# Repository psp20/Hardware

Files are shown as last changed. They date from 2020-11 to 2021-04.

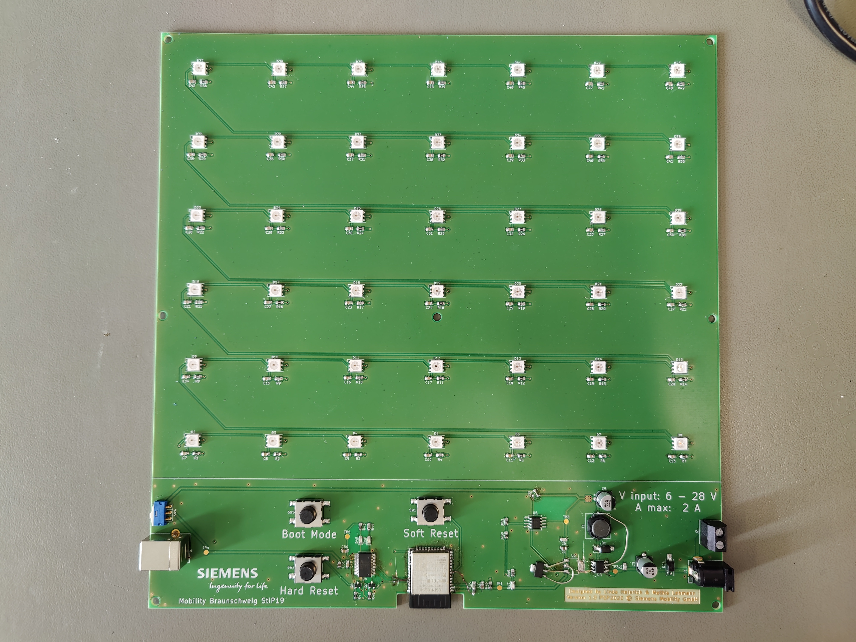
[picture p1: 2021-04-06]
Dokumentation/Anleitung/Bilder/Full.jpg

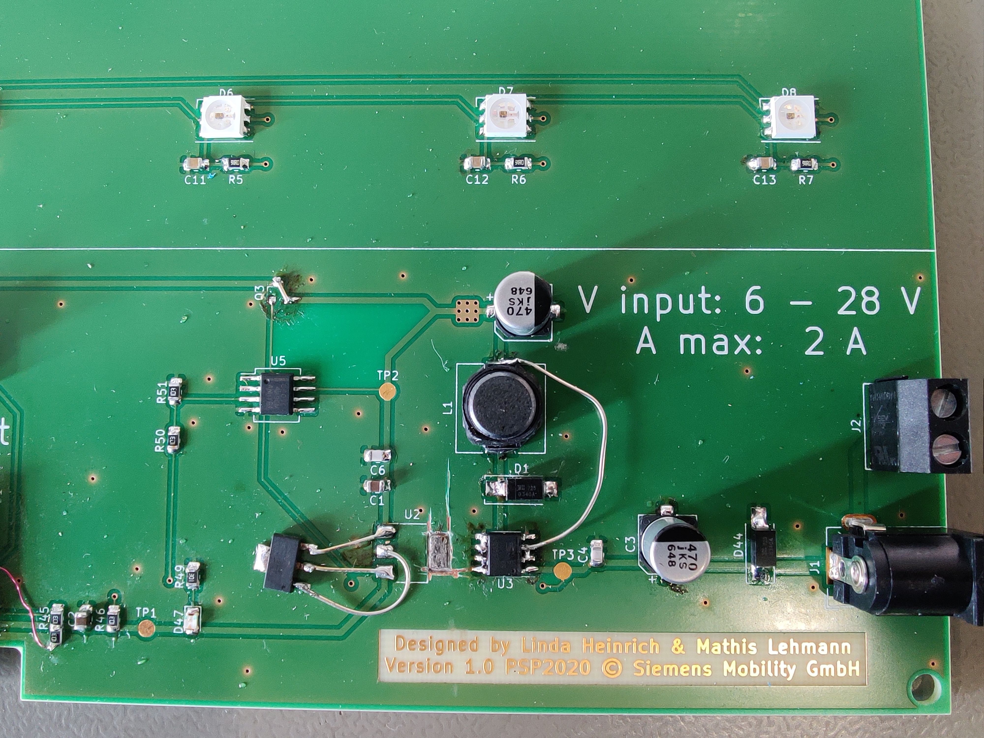
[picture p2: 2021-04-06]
Dokumentation/Anleitung/Bilder/PSU.jpg

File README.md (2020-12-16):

# Hardware
Vier Gewinnt Hardware Repository
## Schaltplan
* [x] Komponenten festlegen
* [x] Schaltplan fertigstellen
* [x] Sanity checks durchführen
* [x] BOM erstellen
## Platinenlayout
* [x] Größe festlegen
* [x] Footprints auswählen
* [x] Trace-routing fertigstellen
## Produktion
* [x] Produktionsmöglichkeiten klären
* [ ] Prototyp bestellen

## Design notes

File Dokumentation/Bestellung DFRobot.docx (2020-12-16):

# Bestellung bei DFRobot

1. DFRobot Prototyping Service aufrufen: Link (https://www.dfrobot.com/index.php?route=product/pcb)
2. Gerber Dateien hochladen –> PSP_Hardware_Gerber.zip
3. Einstellungen anpassen / überprüfen
  a. Layer: 2 Layer
  b. PCB Dimensions: 245 W * 250 L
  c. PCB Qty: 10
  d. Different Design(s): 1
  e. PCB Thickness: 1.6
  f. PCB Color: Black
  g. Surface Finish: HASL
  h. Copper Weight: 1oz
  i. Production Time: 5-6 working days
4. Add To Cart
5. Bestellung abschließen

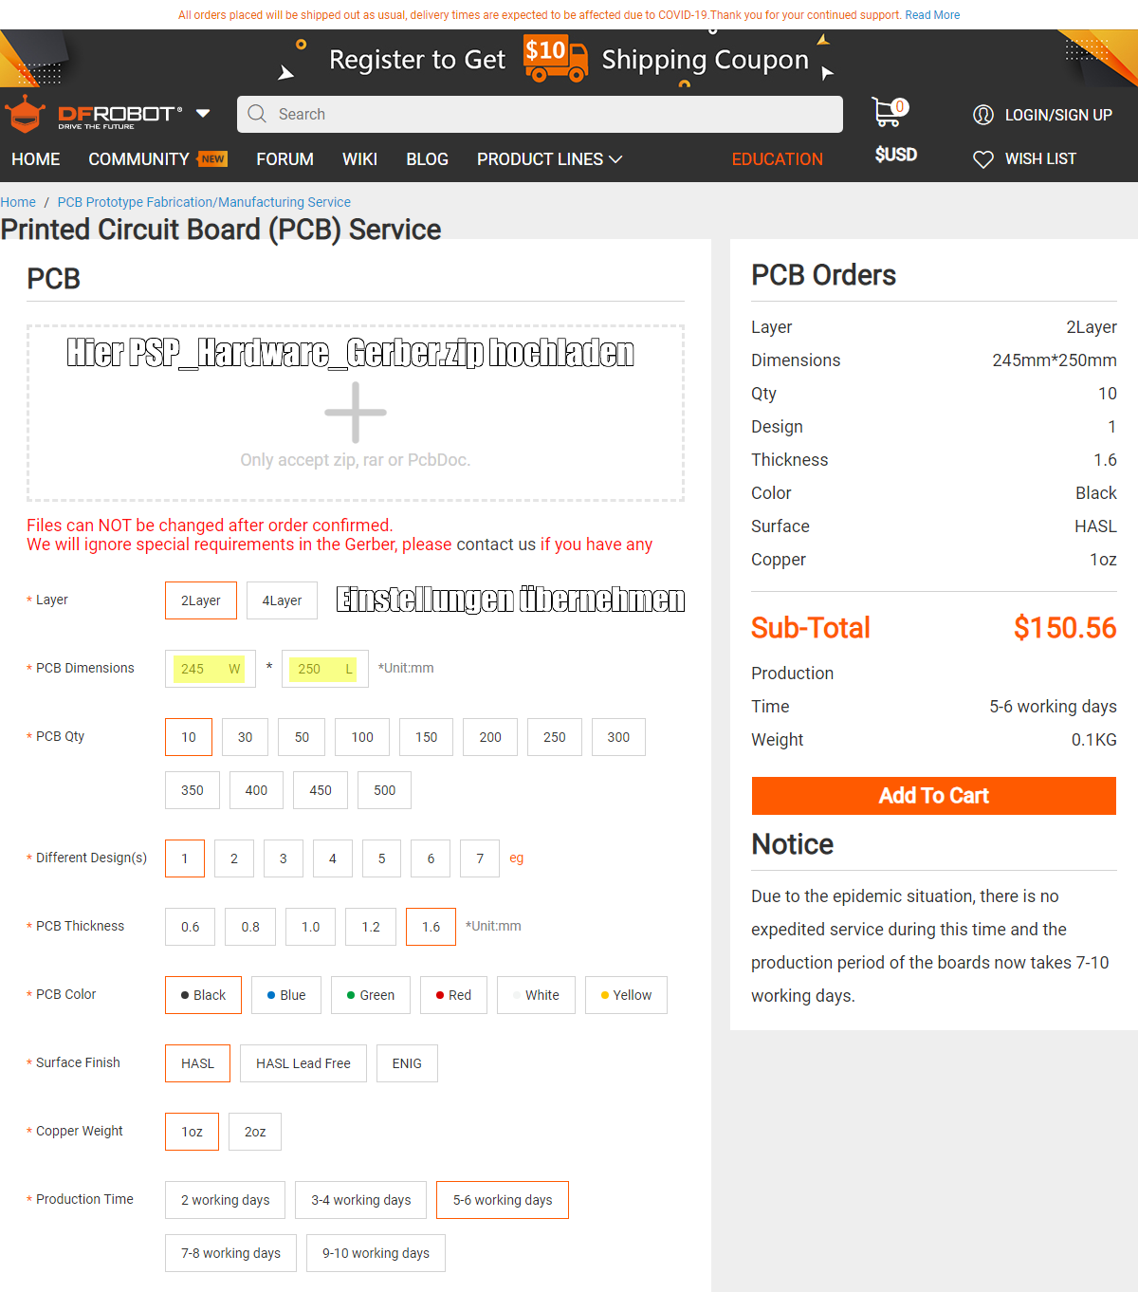
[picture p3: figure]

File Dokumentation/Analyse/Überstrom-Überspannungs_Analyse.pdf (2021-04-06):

## Risikoanalyse eines Überstrom- oder Überspannungsereignisses auf der

## Vier-Gewinnt-Platine

Mathis Lehmann
PSP20
mathis.lehmann@siemens.com Revision V1.0
2. März 2021

1

## Inhaltsverzeichnis

1 Einführung | 3
2 Rundsteckerhohlbuchse | 4
3 Terminal-block | 6
4 USB Typ B Buchse | 8
5 Revisionsverzeichnis | 9

2

## 1 Einführung

### 1.1 Abstrakt

Dieses Dokument befasst sich mit der Analyse eines Überstrom- oder Überspannungsereignisses und den Konsequenzen eines solchen Ereignisses. Es analysiert die Platine und deren Komponenten, welche die Form eines digitalen Vier-Gewinnt einnimmt und im Rahmen des Praxissemsterprojektes bei der Siemens Mobility GmbH von den Dualen Studenten des Jahrgangs 2019 erarbeitet wurden. Das hardwareseitige Produkt dieses Praxissemesters wird im Folgenden nur noch Platine genannt. Hierbei werden Konsequenzen einer eventuell auftretenden Überlast auf die Platine, die verbauten Komponenten und eventuelle Stromquellen betrachtet. Dies soll eine Entscheidung begründen, ob zusätzliche Sicherungsmaßnahmen auf Seiten der Platine zu empfehlen oder gar nötig sind.

### 1.2 Vorgehen

Im weiteren Verlauf dieses Dokuments werden folgendene Szenarien analysiert:

1. Verpolung der angelegten Spannung
2. Zu hohe angelegte Spannung seitens der Spannungsquelle
3. Zu hoher Strom aufgrund eines Fehlers auf der Platine
4. Spannungszusammenbruch auf Seite der Stromquelle

Diese werden jeweils unter einem der 3 Einspeisungspunkte der Platine analysiert:

1. Rundsteckerhohlbuchse
2. Terminal-block
3. USB Typ B Buchse

3

## 2 Rundsteckerhohlbuchse

### 2.1 Verpolung

Eine Verpolung der Rundsteckerhohlbuchse ist sehr unwahrscheinlich, da die Platine die standardisierte Hohlbuchsenbelegung benutzt. Diese benutzt den äußeren Mantel als negativen Pol und den geschützten Innenpin als positiven Pol. Jedoch gibt es Netzteile die dieser Belegung nicht folgen, da sich daraus früher diesen Herstellern gewisse Vorteile boten. Diese Netzteile sind selten, aber dennoch verfügbar und stellen damit ein Risiko für die Platine dar.
Im Falle einer Verpolung greift eine Schutzeinrichtung der Platine, eine Verpolungsdiode. Diese schließt die verkehrt gepolte Spannungsquelle kurz. Diese Diode ist in der Lage 3 Ampere dauerhaft kurzzuschließen. Hieraus ergeben sich folgende Szenarien:
1. Überlastabschaltung des Netzteils löst aus. In diesem Fall schaltet sich das Netzteil zum Selbstschutz aus. Eine Beschädigung der Platine ist höchst unwahrscheinlich, da die Diode eine maximale Belastung von 80 Ampere für 8,3 ms aushält, was ausreichend ist, um selbst überdimensionierte Netzteile in den Überlastzustand zu bringen. Die Diode bleibt davon ungeschädigt und die Platine kann nach beheben der Verpolung weitergenutzt werden.
2. Überlastabschaltung des Netzteils löst nicht aus. In diesem Fall gibt es 2 Unterszenarien:
(a) Netzteil liefert maximal 3 Ampere. In diesem Fall wird das Netzteil dauerhaft kurzgeschlossen, bis der Endbenutzer den Fehler bemerkt oder eine andere Sicherungseinrichtung greift. Die Platine bleibt unbeschädigt.
(b) Netzteil liefert mehr als 3 Ampere. In diesem Fall wird das Netzteil dauerhaft kurzgeschlossen, bis der Endbenutzer den Fehler bemerkt oder eine andere Sicherungseinrichtung greift. Jedoch wurde die Diode dauerhaft überlastet und stellt einen dauerhaften niederohmigen Kurzschluss dar.

### 2.2 Überspannung

Eine Überspannung tritt ab einer Eingangsspannung von 28 Volt auf. Je nach Höhe der Eingangsspannung gibt es hier 2 Fälle:

1. Eingangsspannung von unter 40 Volt. In diesem Fall wird duch die Spannung der Eingangskondensator beschädigt. Dieser wird nach kurzer Zeit das Elektrolyt entlüften und somit zu einem niederohmigen Widerstand, der nun die Spannungsquelle kurzschließt. Bis dies passiert, liegt am Step-Down Regler die Überspannung an. Dieser geht ab 29 Volt in die Abschaltung. Jedoch wird er ab 35 Volt beschädigt, welches sich bei diesem Bauteil als hochohmiger Fehler äußert.

4

2. Eingangsspannung von über 40 Volt. In diesem Fall wird die Diode leitend. Und begrenzt die Spannung auf 40 Volt. Die Beschädigungen aus Punkt 1 gelten weiterhin.

Ab diesem Punkt gelten die Unterszenarien aus 2.1 Unterpunkt 2a und 2b, jedoch weiterhin mit den Beschädigungen des jeweiligen Unterpunktes.

### 2.3 Überstrom

Ein Überstromereignis kann nur bei bei voheriger Beschädigung der Platine oder bei einer Überspannung auftreten. In diesem Fall greifen nur die Unterszenarien aus 2.2.

### 2.4 Spannungszusammenbruch

Sollte die Versorgungsspannung unter 7 Volt zusammenbrechen, schaltet sich der Step-Down Regler ab und aktiviert sich erst nach Erreichen von 7 Volt Eingangsspannung. Die Platine bleibt unbeschädigt.

5

## 3 Terminal-block

### 3.1 Verpolung

Im Falle einer Verpolung greift eine Schutzeinrichtung der Platine, eine Verpolungsdiode. Diese schließt die verkehrt gepolte Spannungsquelle kurz. Diese Diode ist in der Lage 3 Ampere dauerhaft kurzzuschließen. Hieraus ergeben sich folgende Szenarien:

1. Überlastabschaltung des Netzteils löst aus. In diesem Fall schaltet sich das Netzteil zum Selbstschutz aus. Eine Beschädigung der Platine ist höchst unwahrscheinlich, da die Diode eine maximale Belastung von 80 Ampere für 8,3 ms aushält, was ausreichend ist, um selbst überdimensionierte Netzteile in den Überlastzustand zu bringen. Die Diode bleibt davon ungeschädigt und die Platine kann nach beheben der Verpolung weitergenutzt werden.
2. Überlastabschaltung des Netzteils löst nicht aus. In diesem Fall gibt es 2 Unterszenarien:
(a) Netzteil liefert maximal 3 Ampere. In diesem Fall wird das Netzteil dauerhaft kurzgeschlossen, bis der Endbenutzer den Fehler bemerkt oder eine andere Sicherungseinrichtung greift. Die Platine bleibt unbeschädigt.
(b) Netzteil liefert mehr als 3 Ampere. In diesem Fall wird das Netzteil dauerhaft kurzgeschlossen, bis der Endbenutzer den Fehler bemerkt oder eine andere Sicherungseinrichtung greift. Jedoch wurde die Diode dauerhaft überlastet und stellt einen dauerhaften niederohmigen Kurzschluss dar.

### 3.2 Überspannung

Eine Überspannung tritt ab einer Eingangsspannung von 28 Volt auf. Je nach Höhe der Eingangsspannung gibt es hier 2 Fälle:

1. Eingangsspannung von unter 40 Volt. In diesem Fall wird duch die Spannung der Eingangskondensator beschädigt. Dieser wird nach kurzer Zeit das Elektrolyt entlüften und somit zu einem niederohmigen Widerstand, der nun die Spannungsquelle kurzschließt. Bis dies passiert, liegt am Step-Down Regler die Spannung an. Dieser geht ab 29 Volt in die Abschaltung. Jedoch wird er ab 35 Volt beschädigt, welches sich bei diesem Bauteil als hochohmiger Fehler äußert.
2. Eingangsspannung von über 40 Volt. In diesem Fall wird die Diode leitend. Und begrenzt die Spannung auf 40 Volt. Die Beschädigungen aus Punkt 1 gelten weiterhin.

Ab diesem Punkt gelten die Unterszenarien aus 3.1 Unterpunkt 2a und 2b, jedoch weiterhin mit den Beschädigungen des jeweiligen Unterpunktes.

6

### 3.3 Überstrom

Ein Überstromereignis kann nur bei bei voheriger Beschädigung der Platine oder bei einer Überspannung auftreten. In diesem Fall greifen nur die Unterszenarien aus 3.2.

### 3.4 Spannungszusammenbruch

Sollte die Versorgungsspannung unter 7 Volt zusammenbrechen schaltet, sich der Step-Down Regler ab und aktiviert sich erst nach Erreichen von 7 Volt Eingangsspannung. Die Platine bleibt unbeschädigt.

7

## 4 USB Typ B Buchse

### 4.1 Verpolung

Bei einer Verpolung des USB Anschlusses wird der P-Channel MOSFET von Drain zu Source betrieben. Daher ist dieser nicht leitend und es liegt keine Spannung an anderen Bauteilen an, die diese beschädigen könnte.
Wenn jedoch das Vier Gewinnt im Programmiermodus verpolt wird, kann der USB Seriell Wandler beschädigt werden.

### 4.2 Überspannung

Bei Überspannung sind zuerste die LEDs zu betrachten. Da die Versorgung über USB ohne Regulierung direkt auf die 5 Volt Versorungsschiene der Platine geht, liegt jede Überspannung direkt an den LEDs an. Diese sind spezifiziert auf einer Versorungsspannung von 5,3 Volt. Über diese Spannung hinaus können diese beschädigt werden. Jedoch ist nicht abzusehen, ob diese LEDs niederohmig oder hochohmig werden.
Bis 18 Volt bleibt der Microcontroller jedoch geschützt, da dieser hinter einer Regulierungsstufe hängt.
Über 18 Volt hinaus ist die Platine mit hoher Wahrscheinlickeit komplett zerstört.

### 4.3 Überstrom

Ein Überstromereignis kann nur bei voheriger Beschädigung der Platine oder bei einer Überspannung auftreten. In diesem Fall würde die Platine den Strom nicht regulieren, da sich auf die Sicherungsmaßnahmen des Netzteiles verlassen wird. Die Platine verwednet den USB Battery Charging 1.2 Standard. Daher sollte kein Netzteil der Platine mehr als 5 Volt bei 2 Ampere zur Verfügung stellen und beim Überschreiten dieser Lesitungsdaten in die Sicherheitsabschaltung gehen.

### 4.4 Spannungszusammenbruch

Bei Unterschreitung der Betriebsspannung bis zu U ≥ 4 Volt ist die Funktion der Platine nicht eingeschränkt. Ab Unterschreitung von 4 Volt wird der Mikrocontroller nicht mehr mit einer ausreichenden Spannung versorgt und geht in Brown-Out-Reset. Daher erkennt er selbstständig die zu niedrige Spannung und schaltet sich deswegen sicherhaltshalber ab.

8

## 5 Revisionsverzeichnis

- 01.03.2021 Erstveröffentlichung
- 02.03.2021 Kontrolliert von Linda Heinrich

9

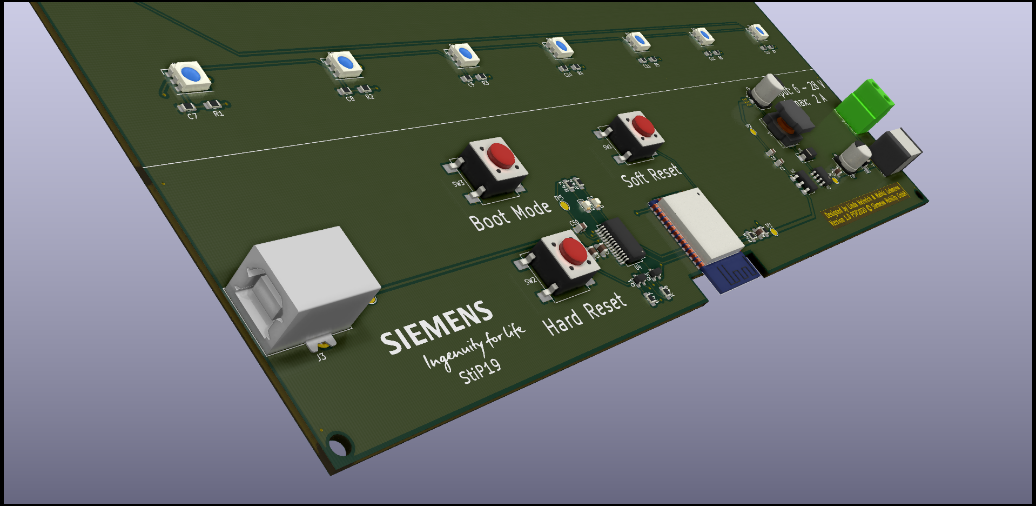
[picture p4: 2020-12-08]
Dokumentation/Platine view 4.png

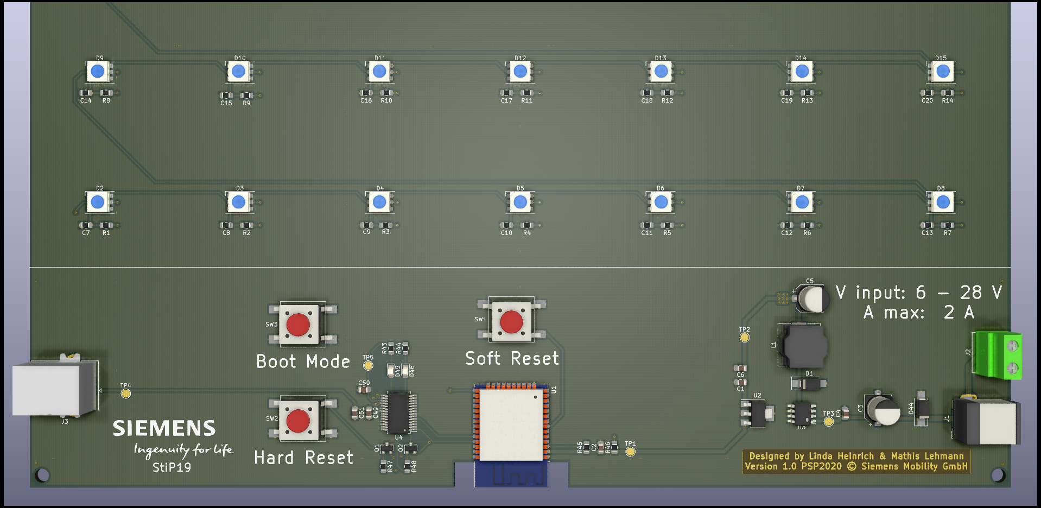
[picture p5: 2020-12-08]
Dokumentation/Platine view 2.png

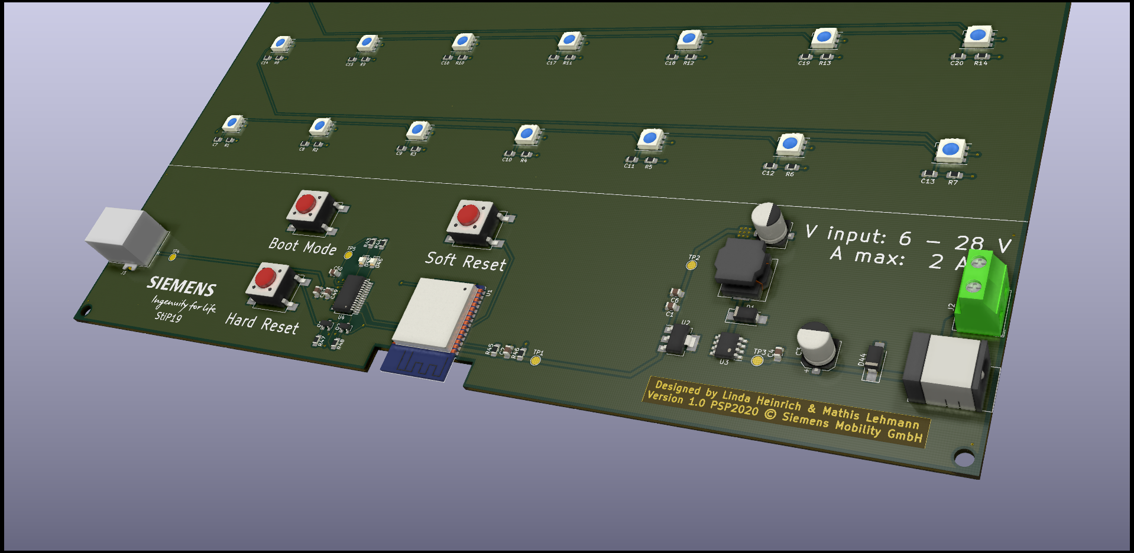
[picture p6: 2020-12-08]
Dokumentation/Platine view 3.png

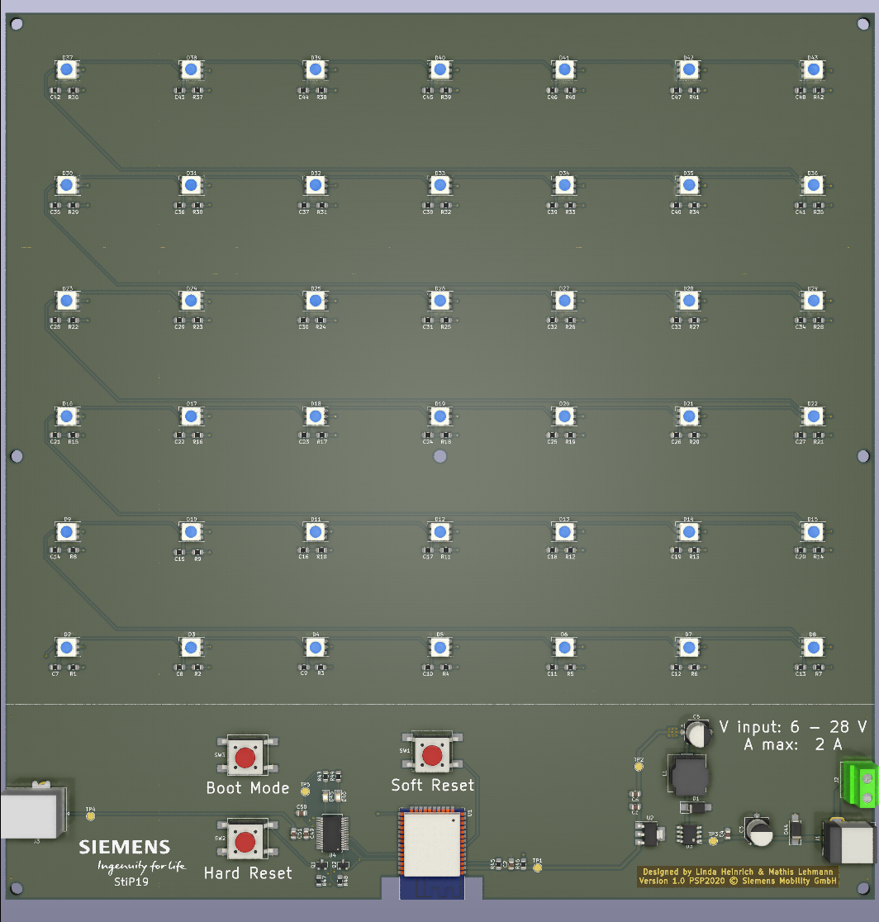
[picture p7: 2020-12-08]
Dokumentation/Platine view 1.png

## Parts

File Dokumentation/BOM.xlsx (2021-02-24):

Anzahl | Bauteil | Wert | Positionen | Reichelt Best Nr. | Conrad Best Nr. | Geprüft | Legacy
1 | LDO | 3.3V 1A | U2 | ZLDO1117G33TA |  | ok
3 | C | 4,7u | C1, C2, C51 | KEM X5R0805 4,7U |  | ok
1 | StepDown | 5V 2A | U3 | TS2596SCS50 |  | ok
2 | D | 40V 3A Schottky | D1, D44 | B340A-13-F DII |  | ok
1 | C | 470u | C5 | FK 470/6,3 SP |  | ok
1 | C | 470u | C3 | ECC MZS350ARA471 |  |  | 60
2 | C | 100p | C4, C6 | KEM C0G0805 100P |  | ok
42 | R | 91R | R1, …, R42 | RND 155HP05 EQ |  | ok
44 | C | 100n | C7, …, C50 | KEM X7R0805 100N |  | ok
1 | U | FT232RL | U4 | FT 232 RL |  | ok
1 | J | USB Type B | J3 | RND 205-00858 |  | ok
2 | D | LED Grün | D45, D47 | EVL 17-21SYGC/S2 |  | ok
1 | D | LED Rot | D46 | KBT KP-2012EC |  | ok
3 | R | 300R | R43, R44, R49 | RND 0805 5 300 |  | ok
3 | SW | SMD Taster | SW1 - SW3 | TASTER 1612.11 |  | ok
2 | Q | NPN Transistor | Q1, Q2 | BCX 19 SMD |  | ok
7 | R | 10k | R45 - R48, R50 - R52 | RND 1550805 DN |  | ok | 60
1 | L | 33uH | L1 | L-PIHV4119 33µ |  | ok
1 | J | Hohlbuchse | J1 | DC-BU 072759 |  | ok
1 | J | Anschlussklemme | J2 | AKL 057-02 |  | ok
1 | SW | THT Schalter 2 Pol | SW4 | SS ESP20 |  | ok
1 | U | OP07 | U5 | OP 07 CD |  | ok
1 | Q | P-FET | Q3 | DMP 3098L7 DII |  | 60 | NDS 0610 SMD
42 | D | RGB | D2, …, D43 |  | 800167562 - VQ | ok
1 | µC | ESP32 WROOM 32D | U1 |  | 1925467 - VQ | ok

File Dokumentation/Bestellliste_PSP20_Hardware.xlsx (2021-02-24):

Anzahl | Kosten | Gesamt | Beschreibung | Reichelt Bestellnummer | Conrad Bestellnummer | Link
60 | 0.35 € | 21.00 € | LDO | ZLDO1117G33TA |  | Link (https://www.reichelt.de/ldo-regler-fest-3-3-v-sot-223-3-zldo1117g33ta-p219149.html?trstct=pos_0&nbc=1) |  | ok
200 | 0.09 € | 18.00 € | C | KEM X5R0805 4,7U |  | Link (https://www.reichelt.de/vielschicht-kerko-4-7-f-25v-85-c-kem-x5r0805-4-7u-p207088.html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) |  | ok
60 | 0.67 € | 40.20 € | U | TS2596SCS50 |  | Link (https://www.reichelt.de/step-down-regler-5v-2a-4-5-24vi-so8-ts2596scs50-p256334.html?trstct=pos_0&nbc=1) |  | 60
200 | 0.19 € | 38.00 € | D | B340A-13-F DII |  | Link (https://www.reichelt.de/gleichrichterdiode-40-v-3-a-sma-b340a-13-f-dii-p216723.html?search=B340A-13-F+DII) |  | ok
200 | 0.25 € | 50.00 € | C | FK 470/6,3 SP |  | Link (https://www.reichelt.de/elko-smd-470-f-6-3v-2000h-low-esr-fk-470-6-3-sp-p175047.html?search=FK+470%2F6%2C3+SP) |  | ok
200 | 0.05 € | 10.00 € | C | KEM C0G0805 100P |  | Link (https://www.reichelt.de/vielschicht-kerko-100pf-50v-125-c-kem-c0g0805-100p-p207035.html?trstct=pol_2&nbc=1) |  | ok
2500 | 0.02 € | 50.00 € | R | RND 155HP05 EQ |  | Link (https://www.reichelt.de/smd-widerstand-0805-91-ohm-330-mw-1--rnd-155hp05-eq-p250837.html?search=RND+155HP05+EQ) |  | ok
2500 | 0.05 € | 125.00 € | C | KEM X7R0805 100N |  | Link (https://www.reichelt.de/vielschicht-kerko-100nf-50v-125-c-kem-x7r0805-100n-p207073.html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) |  | ok
60 | 3.02 € | 181.20 € | U | FT 232 RL |  | Link (https://www.reichelt.de/rs232-interface-bruecke-usb-zu-uart-ssop-28-ft-232-rl-p64399.html?search=FT+232+RL) |  | ok
60 | 0.24 € | 14.40 € | J | RND 205-00858 |  | Link (https://www.reichelt.de/usb-einbaubuchse-typ-b-gewinkelt-printmontage-rnd-205-00858-p253050.html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) |  | ok
200 | 0.07 € | 14.00 € | D | EVL 17-21SYGC/S2 |  | Link (https://www.reichelt.de/led-smd-0805-gruen-17-mcd-140--evl-17-21sygc-s2-p231645.html?trstct=pos_0&nbc=1) |  | ok
100 | 0.09 € | 9.00 € | D | KBT KP-2012EC |  | Link (https://www.reichelt.de/led-smd-0805-rot-12-mcd-120--kbt-kp-2012ec-p231678.html?&trstct=pos_0&nbc=1) |  | ok
200 | 0.01 € | 2.40 € | R | RND 0805 5 300 |  | Link (https://www.reichelt.de/smd-widerstand-0805-300-ohm-125-mw-5--rnd-0805-5-300-p183218.html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) |  | ok
160 | 0.84 € | 134.40 € | SW | TASTER 1612.11 |  | Link (https://www.reichelt.de/smd-taster-oberflaechenmontage-hoehe-7-8mm-taster-1612-11-p44474.html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) |  | ok
150 | 0.04 € | 6.00 € | Q | BCX 19 SMD |  | Link (https://www.reichelt.de/bipolartransistor-npn-45v-0-5a-0-25w-sot-23-bcx-19-smd-p90184.html?search=BCX+19+SMD) |  | ok
400 | 0.02 € | 8.00 € | R | RND 1550805 DN |  | Link (https://www.reichelt.de/smd-widerstand-0805-10-kohm-125-mw-5--rnd-1550805-dn-p250310.html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) |  | ok
60 | 0.82 € | 49.20 € | L | L-PIHV4119 33µ |  | Link (https://www.reichelt.de/chip-induktivitaet-pihv4119-33-h-l-pihv4119-33--p255630.html?search=L-PIHV4119+33µ) |  | ok
60 | 1.46 € | 87.60 € | J | DC-BU 072759 |  | Link (https://www.reichelt.de/einbaubuchse-aussen-6-3-mm-innen-2-1-mm-dc-bu-072759-p208065.html?trstct=pos_0&nbc=1) |  | 6
60 | 0.21 € | 12.60 € | J | AKL 057-02 |  | Link (https://www.reichelt.de/anschlussklemme-2-pol-2-mm-rm-5-08-akl-057-02-p36615.html?trstct=pos_0&nbc=1) |  | ok
60 | 0.77 € | 46.20 € | SW | SS ESP20 |  | Link (https://www.reichelt.de/schiebeschalter-1x-um-liegend-print-rm-2-54-ss-esp201-p112179.html?trstct=pos_0&nbc=1) |  | ok
60 | 0.29 € | 17.40 € | U | OP 07 CD |  | Link (https://www.reichelt.de/operationsverstaerker-1-fach-so-8-op-07-cd-p39828.html?&trstct=pos_0&nbc=1) |  | ok
60 | 0.12 € | 7.20 € | Q | NDS 0610 SMD |  | Link (https://www.reichelt.de/mosfet-p-ch-60v-0-12a-0-36w-sot-23-nds-0610-smd-p115905.html?search=NDS+0610+SMD) |  | 50
250 | 1.31 € | 327.50 € | D |  | 800167562-62 | Link (https://www.conrad.de/de/p/hc-ws2812s-led-led-5050-rgb-620-515-465nm-700-1400-400mcd-20ma-160-driver-inhalt-10-stueck-800167562.html) | Achtung 10er Pack als Bestelleinheit. 2500 Stück gesamt. 250 Bestelleinheiten. | 250
60 | 4.38 € | 262.80 € | U |  | 1925467-62 | Link (https://www.conrad.de/de/p/espressif-esp32-wroom-32d-funkmodul-1925467.html) |  | 60
Gesamt |  | 1532.10 €

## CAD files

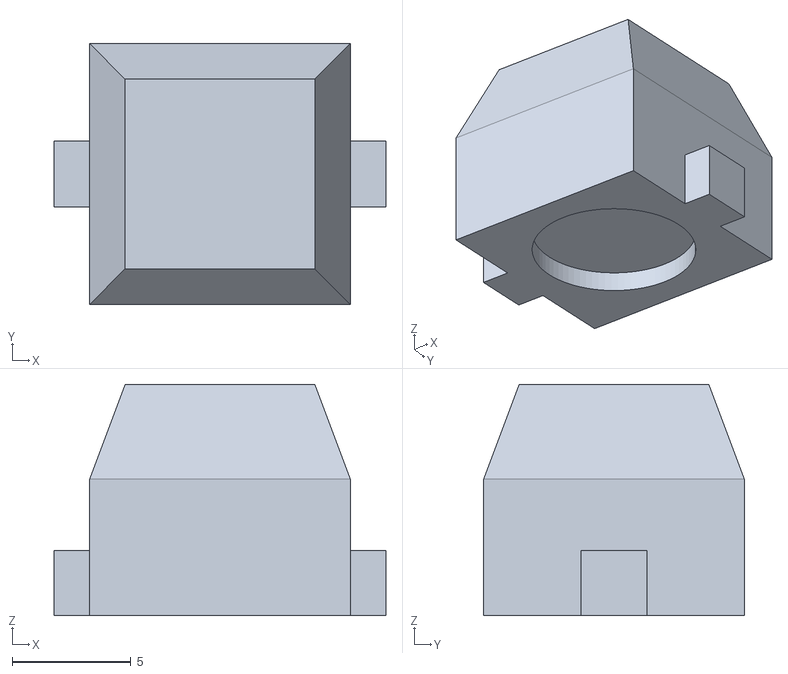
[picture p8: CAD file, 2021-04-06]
Gehäuse/Taster_einzeln.stl
14.0 x 11.0 x 9.75

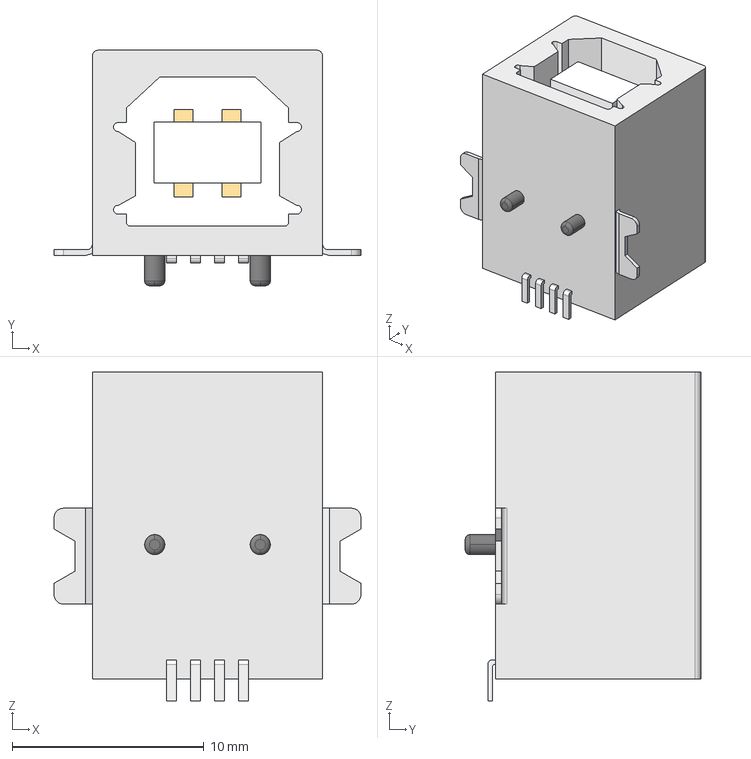
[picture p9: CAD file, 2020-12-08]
Platine/3D Models/usb_a-usb_b_smt-r.stp
16.0 x 12.3 x 17.1 mm

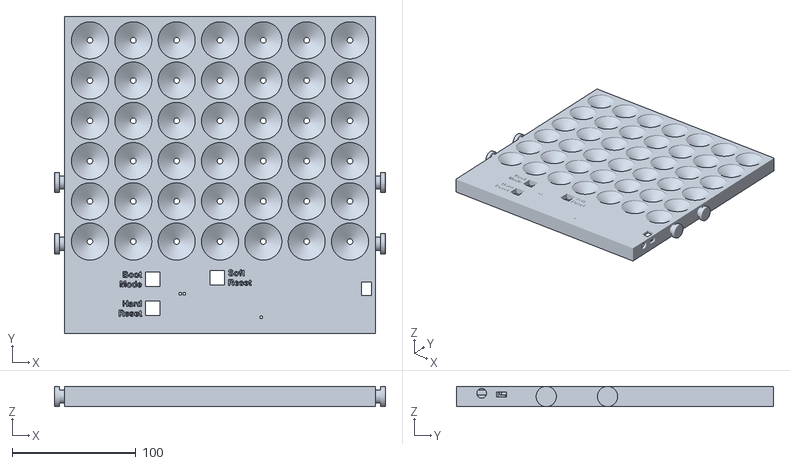
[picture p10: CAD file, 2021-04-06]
Gehäuse/GehäuseVorderseite.stl
267.5 x 256.0 x 16.4

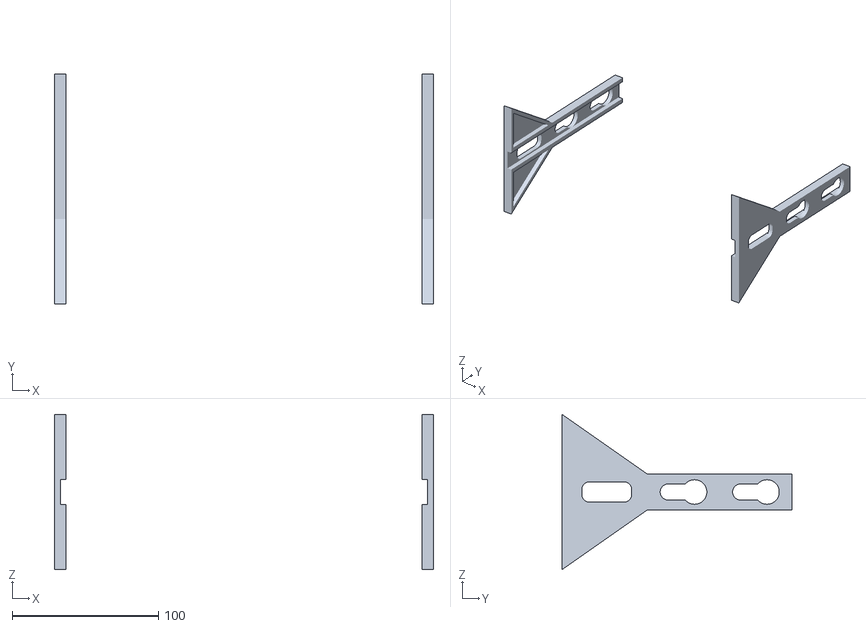
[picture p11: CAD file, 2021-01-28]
Gehäuse/Standfüße.stl
259.0 x 157.0 x 106.0

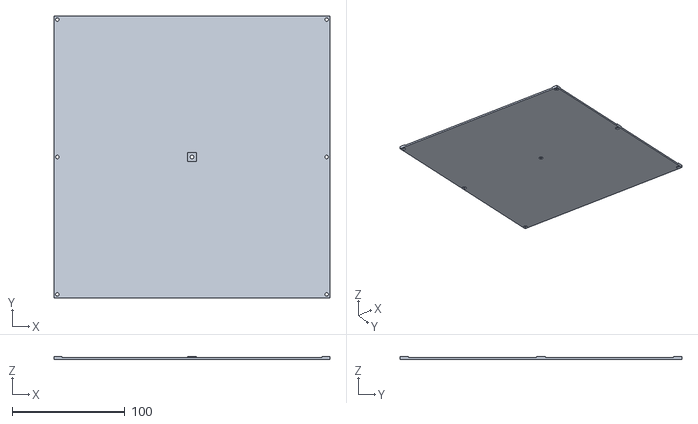
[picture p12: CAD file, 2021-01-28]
Gehäuse/GehäuseRückseite.stl
245.0 x 250.0 x 3.00

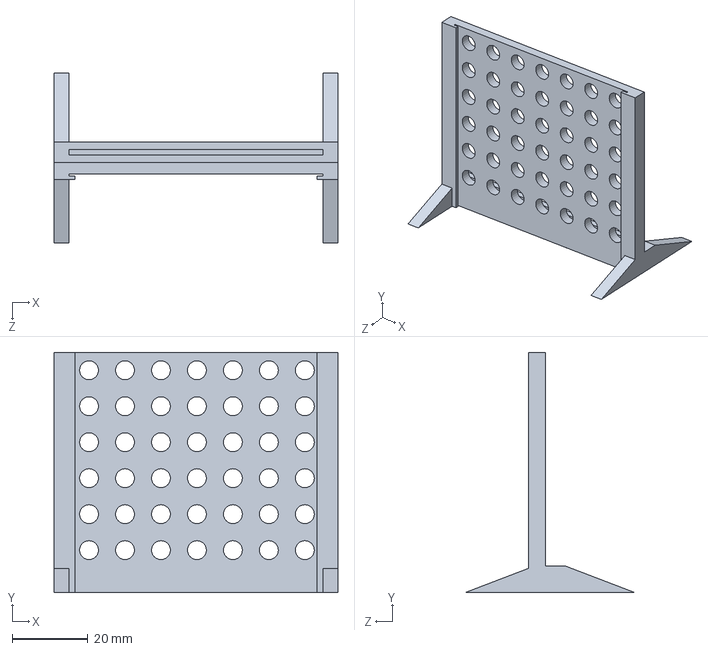
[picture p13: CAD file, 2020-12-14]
Gehäuse/Prototyp V2.SLDPRT
75.0 x 63.5 x 45.0 mm

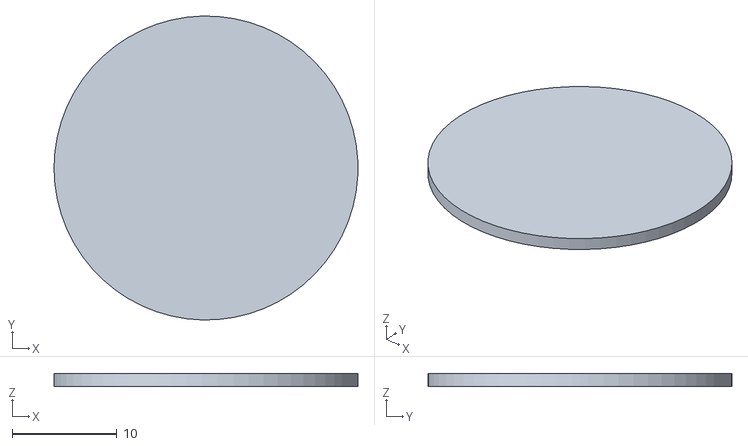
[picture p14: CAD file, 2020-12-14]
Gehäuse/Linse.STL
29.0 x 29.0 x 1.20

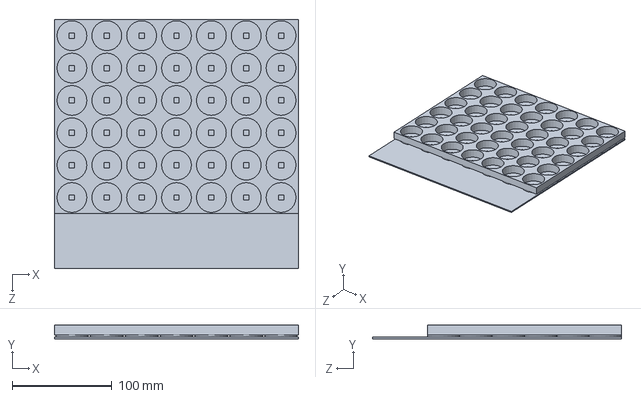
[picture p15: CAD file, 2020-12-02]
Gehäuse/Platinen Mockup.SLDPRT
245.0 x 13.6 x 250.0 mm

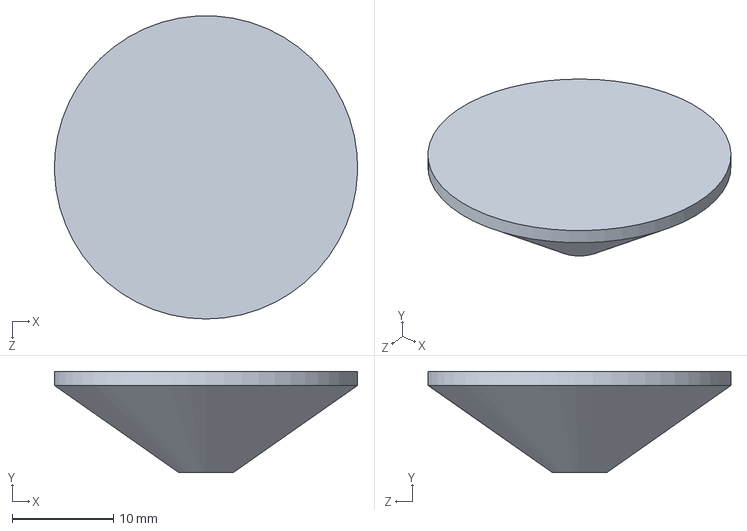
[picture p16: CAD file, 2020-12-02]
Gehäuse/Diffusor.SLDPRT
30.0 x 10.0 x 30.0 mm

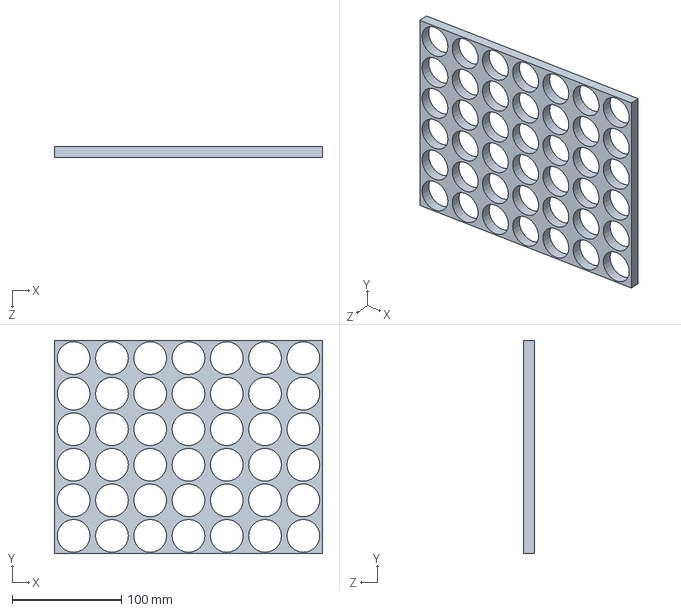
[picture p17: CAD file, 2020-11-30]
Gehäuse/Blendenmatrix.SLDPRT
245.0 x 195.0 x 10.0 mm

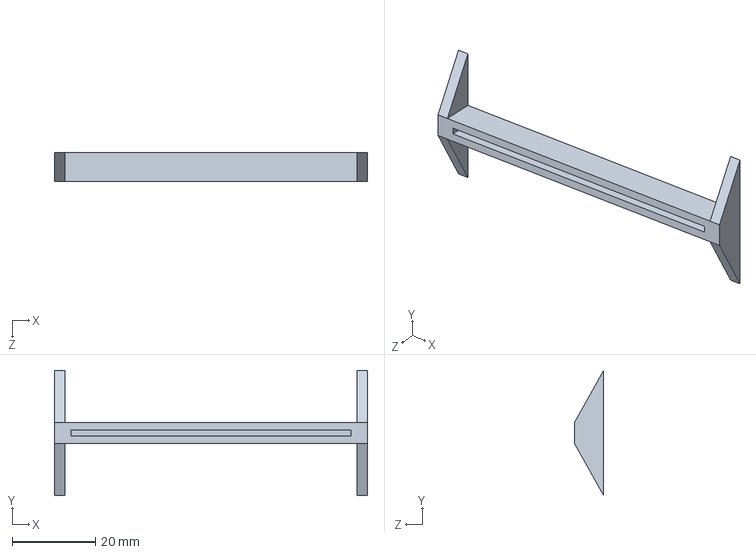
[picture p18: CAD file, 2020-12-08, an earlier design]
Gehäuse/Prototyp.SLDPRT
75.0 x 30.0 x 7.00 mm

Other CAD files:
Gehäuse/Blendenmatrix.AMF
Gehäuse/Gehäuse_v31.f3d
Gehäuse/Prototyp V2.STL
Gehäuse/Prototyp.STL

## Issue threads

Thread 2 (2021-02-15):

Isolate tab of ZLDO 17-33 from groundplane

dl7mlp, 2021-02-15:
Isolate tab of ZLDO 17-33 from groundplane to remove short circuit

Closed 2021-02-24.

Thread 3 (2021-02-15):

Edit power figures on silkscreen

dl7mlp, 2021-02-15:
Increase low input voltage minimum from 6V to 7V to conform datasheet

dl7mlp, 2021-02-17:
Mark positive and negative on terminal-block as well

Closed 2021-02-24.

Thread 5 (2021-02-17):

Switch TX & RX

dl7mlp, 2021-02-17:
Switch RX & TX from FT232RL and ES32

dl7mlp, 2021-02-24:
Fixed in Commit [https://github.com/psp20/Hardware/commit/d5fd517fe7852fd6d15fd315cc994aaa656012c1](url)

Closed 2021-02-24.

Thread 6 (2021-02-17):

Switch drain and source of P-FET

dl7mlp, 2021-02-17:
Switch drain and source of P-FET

dl7mlp, 2021-02-24:
Fixed in commit [https://github.com/psp20/Hardware/commit/230d3134c3d11bb4584f2c876f4e6aad84807237](url)

Closed 2021-02-24.

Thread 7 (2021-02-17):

Change P-FET to 2A continues capable model

dl7mlp, 2021-02-17:

dl7mlp, 2021-02-24:
Fixed in commit [https://github.com/psp20/Hardware/commit/230d3134c3d11bb4584f2c876f4e6aad84807237](url)

Closed 2021-02-24.

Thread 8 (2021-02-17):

Correctly use common of switch for USB V IN

dl7mlp, 2021-02-17:
Correctly use common (middle pin) of switch for USB V IN

dl7mlp, 2021-02-24:
Switch is not used to switch 5V rail on the board. Only FT232RL is switched!

Closed 2021-02-24.

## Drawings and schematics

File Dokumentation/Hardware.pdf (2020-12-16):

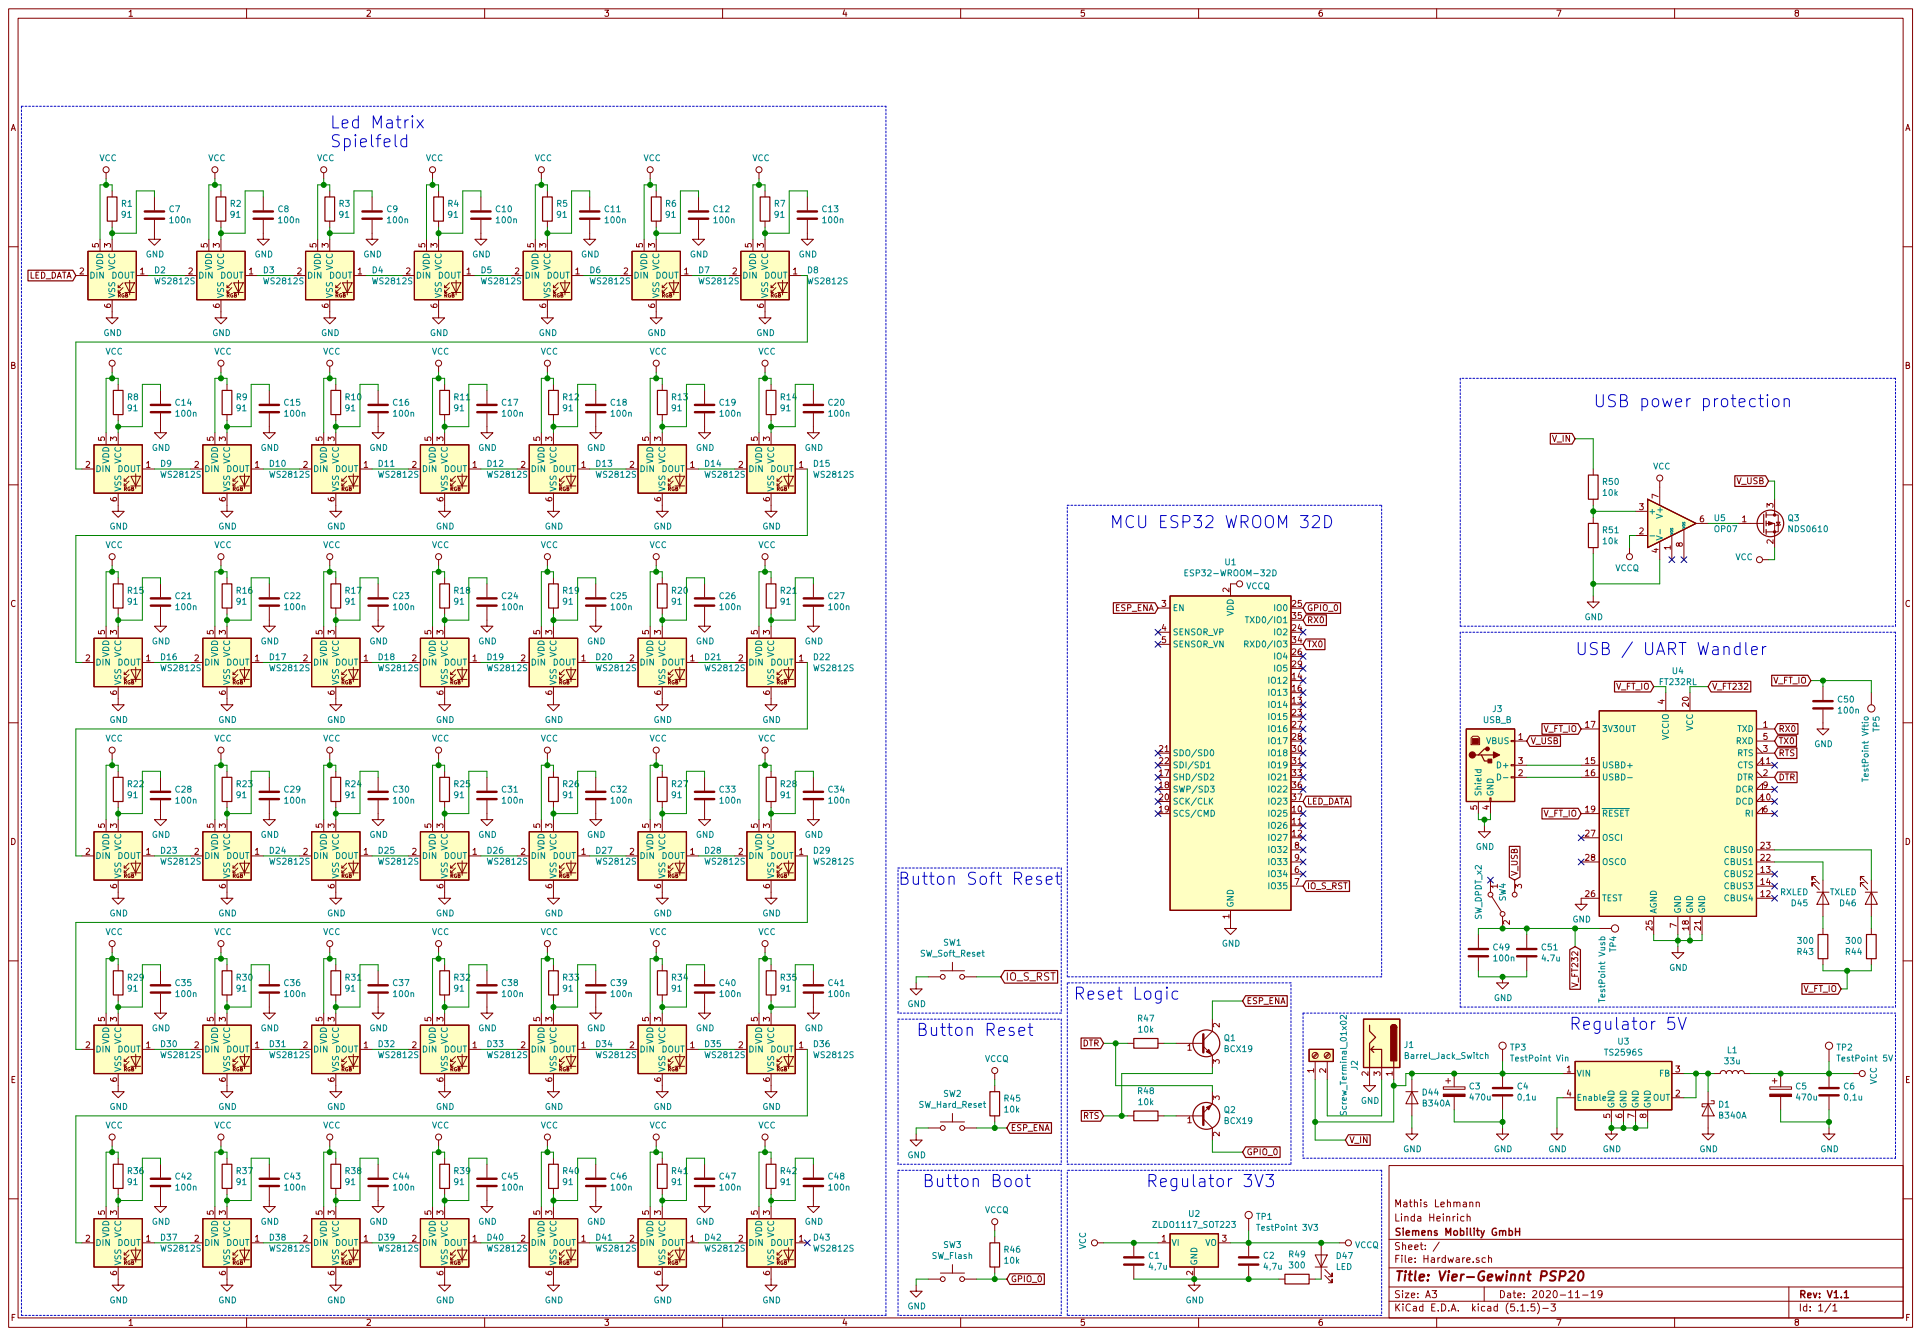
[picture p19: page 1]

2 SCK/CLK 20 SDO/SD0 21 SDI/SD1 22

Linda Heinrich Mathis Lehmann R27

Button Reset | | 10k VCCQ ESP_ENA

Button Boot 10k GND | Regulator 3V3

File: Hardware.sch Sheet: / Siemens Mobility GmbH

VCCQ
Id: 1/1 Title: Vier-Gewinnt PSP20

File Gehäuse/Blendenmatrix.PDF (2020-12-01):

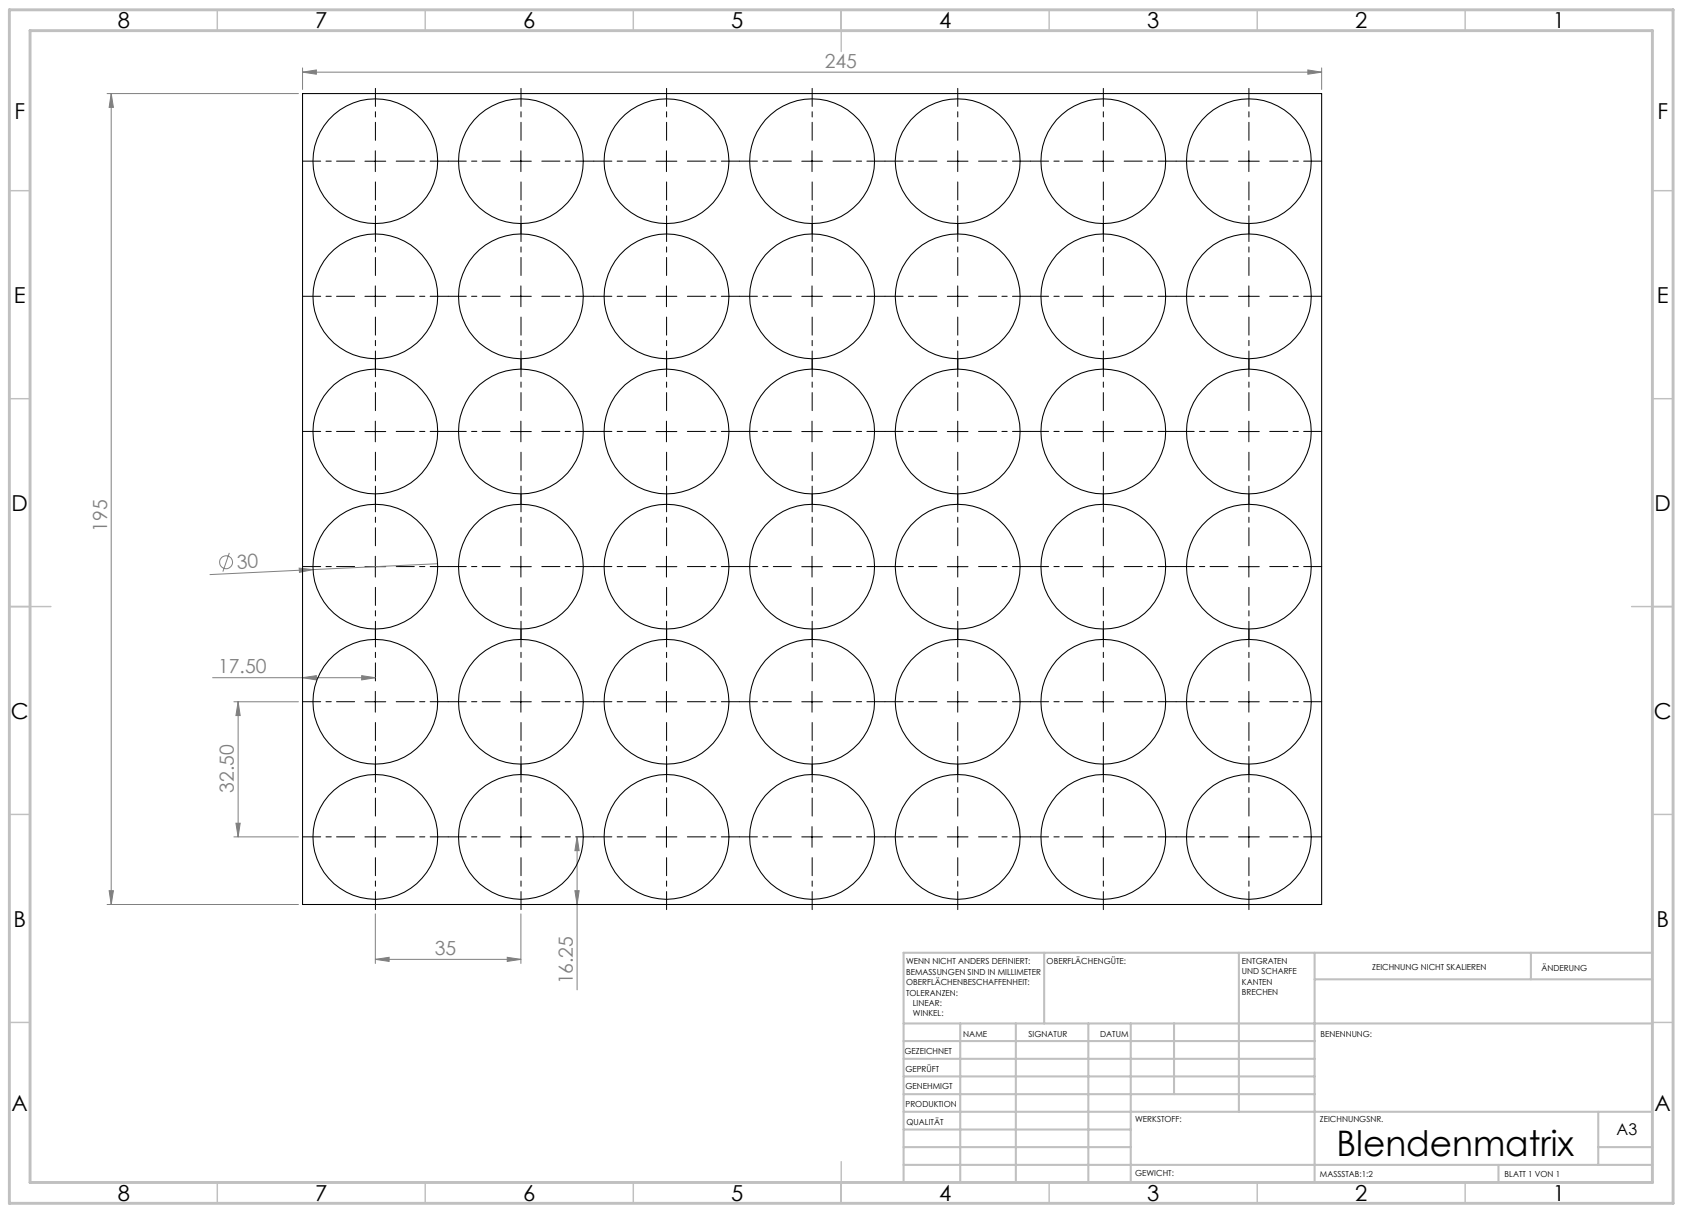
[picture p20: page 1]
MASSSTAB:1:2; BLATT 1 VON 1; ZEICHNUNG NICHT SKALIEREN; ÄNDERUNG; UND SCHARFE; WENN NICHT ANDERS DEFINIERT:; OBERFLÄCHENGÜTE:

BEMASSUNGEN SIND IN MILLIMETER
OBERFLÄCHENBESCHAFFENHEIT:
TOLERANZEN:
LINEAR:
WINKEL:

NAME | SIGNATUR | DATUM | | | | BENENNUNG:
QUALITÄT | | | | WERKSTOFF: | ZEICHNUNGSNR. Blendenmatrix GEWICHT: | A3

GEZEICHNET
GEPRÜFT
GENEHMIGT
PRODUKTION

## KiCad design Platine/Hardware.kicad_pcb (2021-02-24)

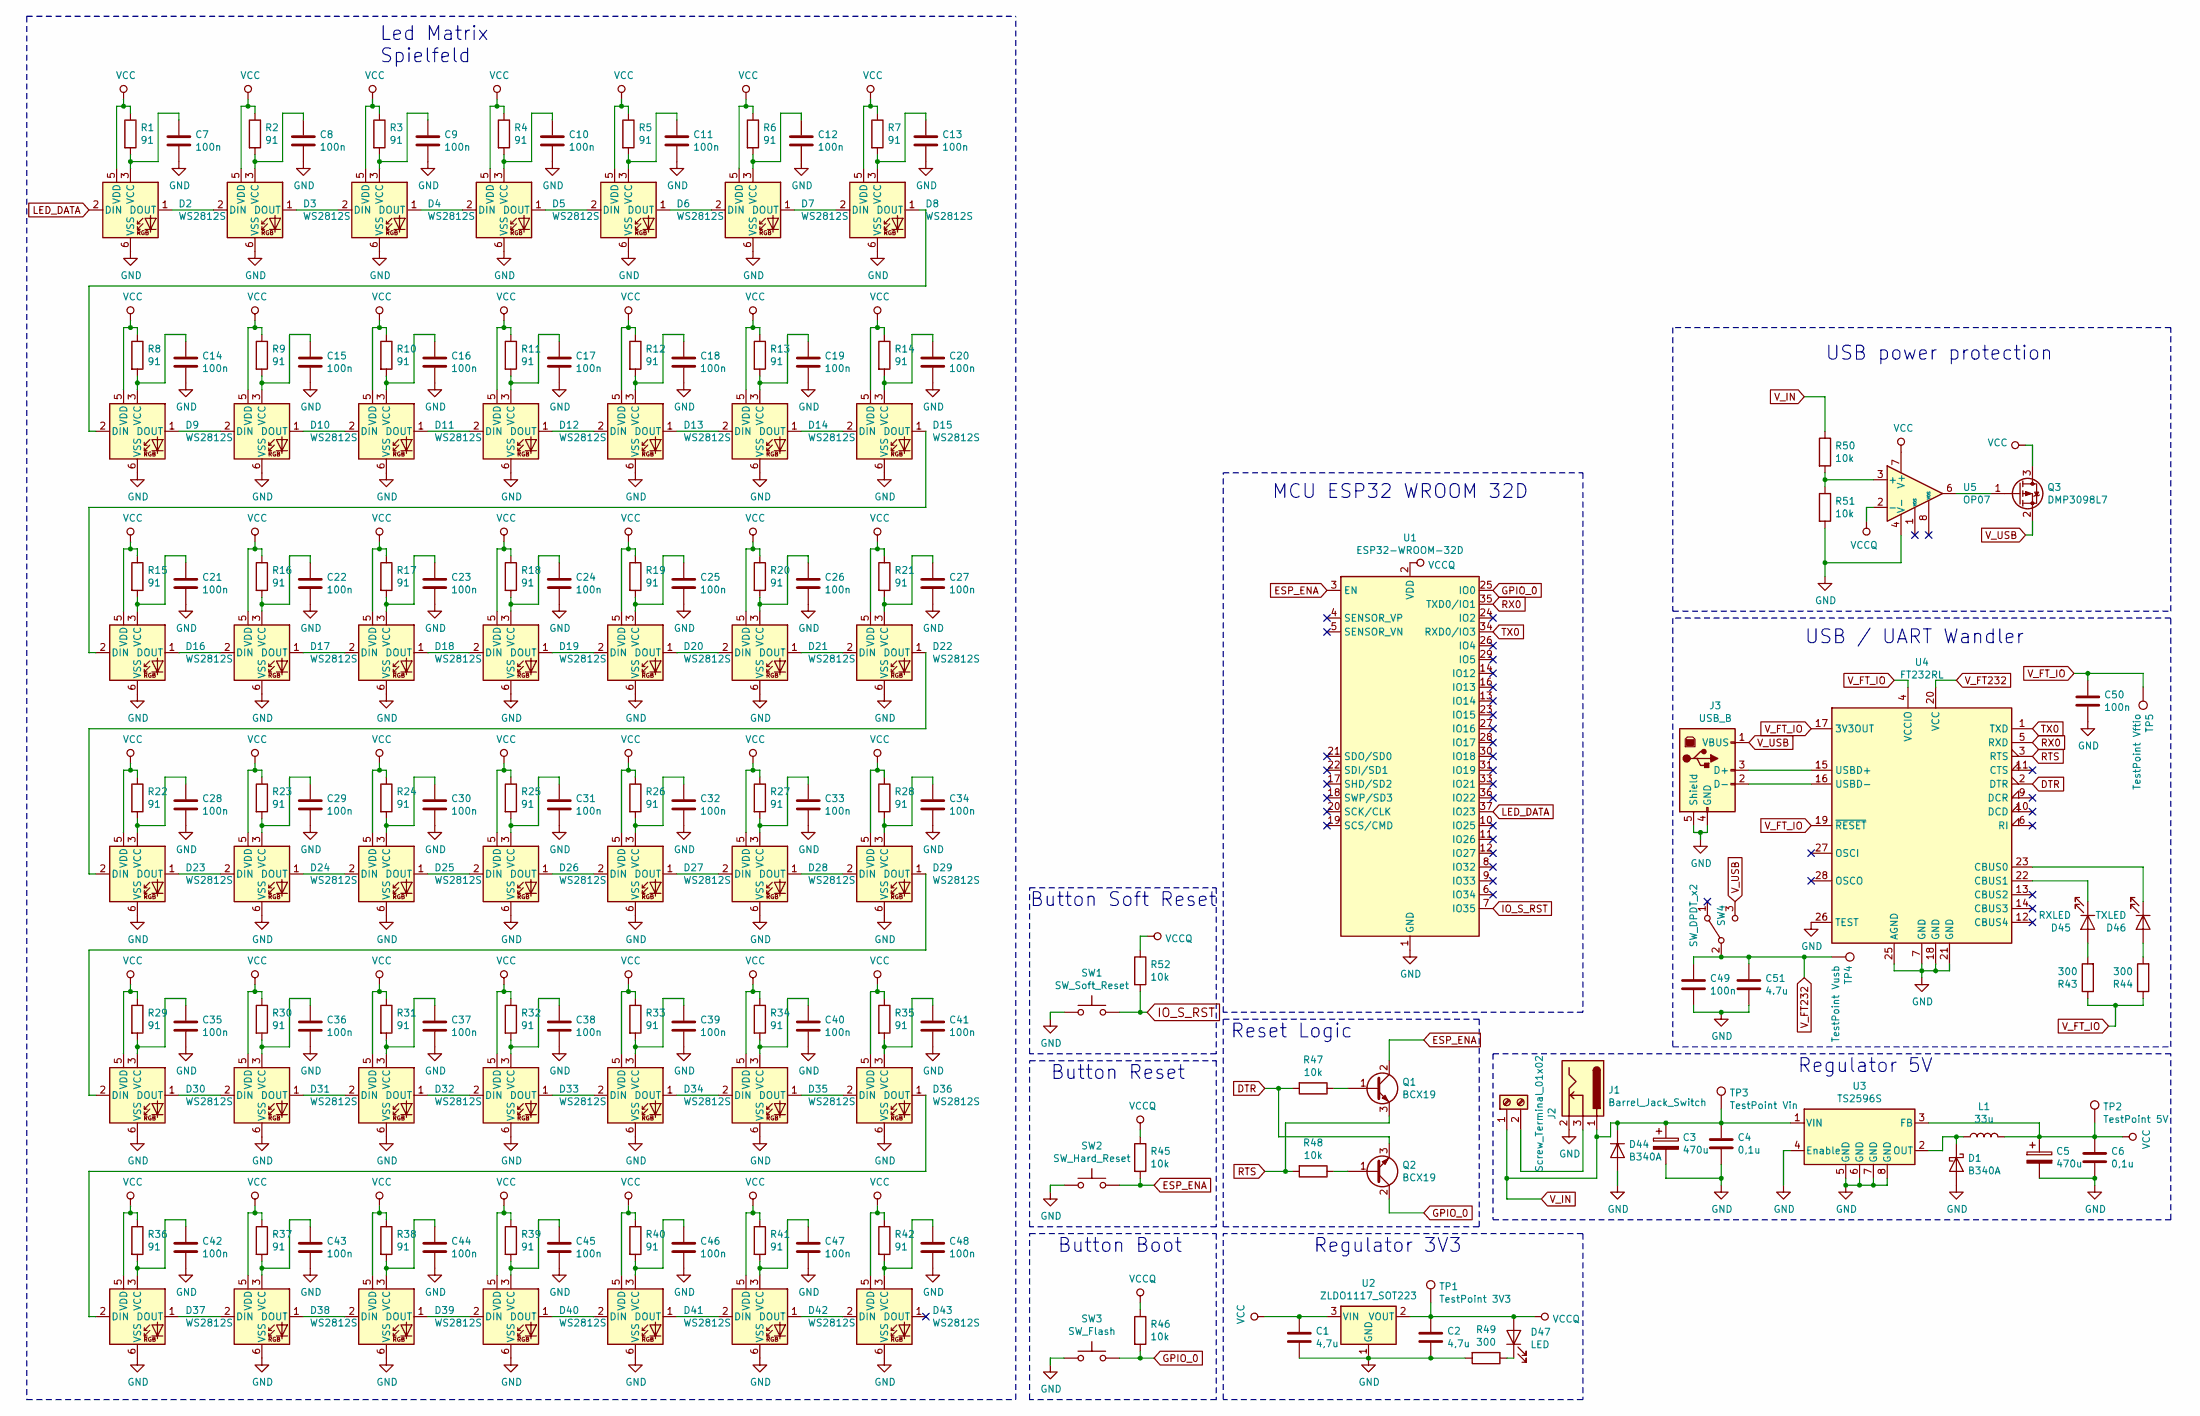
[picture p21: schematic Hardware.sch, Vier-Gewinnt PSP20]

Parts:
C1, C2: 4,7u; C_0805_2012Metric_Pad1.15x1.40mm_HandSolder
C3: 470u; CP_Elec_8x10
C4, C6: 0,1u; C_0805_2012Metric_Pad1.15x1.40mm_HandSolder
C5: 470u; CP_Elec_6.3x7.7
C7, C8, C9, C10, C11, C12, C13, C14, C15, C16, C17, C18, C19, C20, C21, C22, C23, C24, C25, C26, C27, C28, C29, C30, C31, C32, C33, C34, C35, C36, C37, C38, C39, C40, C41, C42, C43, C44, C45, C46, C47, C48: 100n; R_0805_2012Metric_Pad1.15x1.40mm_HandSolder
C49, C50: 100n; C_0805_2012Metric_Pad1.15x1.40mm_HandSolder
C51: 4.7u; C_0805_2012Metric_Pad1.15x1.40mm_HandSolder
D1, D44: B340A; D_SMA_Handsoldering
D2, D3, D4, D5, D6, D7, D8, D9, D10, D11, D12, D13, D14, D15, D16, D17, D18, D19, D20, D21, D22, D23, D24, D25, D26, D27, D28, D29, D30, D31, D32, D33, D34, D35, D36, D37, D38, D39, D40, D41, D42, D43: WS2812S; LED_WS2812_PLCC6_5.0x5.0mm_P1.6mm
D45: RXLED; LED_0805_2012Metric_Pad1.15x1.40mm_HandSolder
D46: TXLED; LED_0805_2012Metric_Pad1.15x1.40mm_HandSolder
D47: LED; LED_0805_2012Metric_Pad1.15x1.40mm_HandSolder
J1: Barrel_Jack_Switch; BarrelJack_BKL_072759
J2: Screw_Terminal_01x02; TerminalBlock_RND_205-00001_1x02_P5.00mm_Horizontal
J3: USB_B; USB_B_OST_USB-B1HSxx_Horizontal
L1: 33u; L_10.4x10.4_H4.8
Q1, Q2: BCX19; SOT-23
Q3: DMP3098L7; SOT-23
R1, R2, R3, R4, R5, R6, R7, R8, R9, R10, R11, R12, R13, R14, R15, R16, R17, R18, R19, R20, R21, R22, R23, R24, R25, R26, R27, R28, R29, R30, R31, R32, R33, R34, R35, R36, R37, R38, R39, R40, R41, R42: 91; R_0805_2012Metric_Pad1.15x1.40mm_HandSolder
R43, R44, R49: 300; R_0805_2012Metric_Pad1.15x1.40mm_HandSolder
R45, R46, R47, R48, R50, R51, R52: 10k; R_0805_2012Metric_Pad1.15x1.40mm_HandSolder
SW1: SW_Soft_Reset; SW_1612.11
SW2: SW_Hard_Reset; SW_1612.11
SW3: SW_Flash; SW_1612.11
SW4: SW_DPDT_x2; Switch
TP1: TestPoint 3V3; TestPoint_Pad_D2.0mm
TP2: TestPoint 5V; TestPoint_Pad_D2.0mm
TP3: TestPoint Vin; TestPoint_Pad_D2.0mm
TP4: TestPoint Vusb; TestPoint_Pad_D2.0mm
TP5: TestPoint Vftio; TestPoint_Pad_D2.0mm
U1: ESP32-WROOM-32D; ESP32-WROOM-32
U2: ZLDO1117_SOT223; SOT-223-3_TabPin2
U3: TS2596S; SOP-8_3.76x4.96mm_P1.27mm
U4: FT232RL; SSOP-28_5.3x10.2mm_P0.65mm
U5: OP07; SO-8_5.3x6.2mm_P1.27mm

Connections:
DTR: Q2.3 (E), R47.2, U4.2 (DTR)
ESP_ENA: Q1.2 (C), R45.2, SW2.2, U1.3 (EN)
GND: C1.2, C2.2, C3.2, C4.2, C5.2, C6.2, C7.1, C8.1, C9.1, C10.1, C11.1, C12.1, C13.1, C14.1, C15.1, C16.1, C17.1, C18.1, C19.1, C20.1, C21.1, C22.1, C23.1, C24.1, C25.1, C26.1, C27.1, C28.1, C29.1, C30.1, C31.1, C32.1, C33.1, C34.1, C35.1, C36.1, C37.1, C38.1, C39.1, C40.1, C41.1, C42.1, C43.1, C44.1, C45.1, C46.1, C47.1, C48.1, C49.2, C50.2, C51.2, D1.2 (A), D2.6 (VSS), D3.6 (VSS), D4.6 (VSS), D5.6 (VSS), D6.6 (VSS), D7.6 (VSS), D8.6 (VSS), D9.6 (VSS), D10.6 (VSS), D11.6 (VSS), D12.6 (VSS), D13.6 (VSS), D14.6 (VSS), D15.6 (VSS), D16.6 (VSS), D17.6 (VSS), D18.6 (VSS), D19.6 (VSS), D20.6 (VSS), D21.6 (VSS), D22.6 (VSS), D23.6 (VSS), D24.6 (VSS), D25.6 (VSS), D26.6 (VSS), D27.6 (VSS), D28.6 (VSS), D29.6 (VSS), D30.6 (VSS), D31.6 (VSS), D32.6 (VSS), D33.6 (VSS), D34.6 (VSS), D35.6 (VSS), D36.6 (VSS), D37.6 (VSS), D38.6 (VSS), D39.6 (VSS), D40.6 (VSS), D41.6 (VSS), D42.6 (VSS), D43.6 (VSS), D44.2 (A), J1.2, J3.4 (GND), J3.5 (Shield), R49.2, R51.2, SW1.1, SW2.1, SW3.1, U1.1 (GND), U1.15 (GND), U1.38 (GND), U1.39 (GND), U2.1 (GND), U3.4 (Enable), U3.5 (GND), U3.6 (GND), U3.7 (GND), U3.8 (GND), U4.7 (GND), U4.18 (GND), U4.21 (GND), U4.25 (AGND), U4.26 (TEST), U5.4 (V-)
GPIO_0: Q2.2 (C), R46.2, SW3.2, U1.25 (IO0)
IO_S_RST: R52.2, SW1.2, U1.7 (IO35)
LED_DATA: D2.2 (DIN), U1.37 (IO23)
unnamed: C7.2, D2.3 (VCC), R1.2
unnamed: C8.2, D3.3 (VCC), R2.2
unnamed: C9.2, D4.3 (VCC), R3.2
unnamed: C10.2, D5.3 (VCC), R4.2
unnamed: C11.2, D6.3 (VCC), R5.2
unnamed: C12.2, D7.3 (VCC), R6.2
unnamed: C13.2, D8.3 (VCC), R7.2
unnamed: C14.2, D9.3 (VCC), R8.2
unnamed: C15.2, D10.3 (VCC), R9.2
unnamed: C16.2, D11.3 (VCC), R10.2
unnamed: C17.2, D12.3 (VCC), R11.2
unnamed: C18.2, D13.3 (VCC), R12.2
unnamed: C19.2, D14.3 (VCC), R13.2
unnamed: C20.2, D15.3 (VCC), R14.2
unnamed: C21.2, D16.3 (VCC), R15.2
unnamed: C22.2, D17.3 (VCC), R16.2
unnamed: C23.2, D18.3 (VCC), R17.2
unnamed: C24.2, D19.3 (VCC), R18.2
unnamed: C25.2, D20.3 (VCC), R19.2
unnamed: C26.2, D21.3 (VCC), R20.2
unnamed: C27.2, D22.3 (VCC), R21.2
unnamed: C28.2, D23.3 (VCC), R22.2
unnamed: C29.2, D24.3 (VCC), R23.2
unnamed: C30.2, D25.3 (VCC), R24.2
unnamed: C31.2, D26.3 (VCC), R25.2
unnamed: C32.2, D27.3 (VCC), R26.2
unnamed: C33.2, D28.3 (VCC), R27.2
unnamed: C34.2, D29.3 (VCC), R28.2
unnamed: C35.2, D30.3 (VCC), R29.2
unnamed: C36.2, D31.3 (VCC), R30.2
unnamed: C37.2, D32.3 (VCC), R31.2
unnamed: C38.2, D33.3 (VCC), R32.2
unnamed: C39.2, D34.3 (VCC), R33.2
unnamed: C40.2, D35.3 (VCC), R34.2
unnamed: C41.2, D36.3 (VCC), R35.2
unnamed: C42.2, D37.3 (VCC), R36.2
unnamed: C43.2, D38.3 (VCC), R37.2
unnamed: C44.2, D39.3 (VCC), R38.2
unnamed: C45.2, D40.3 (VCC), R39.2
unnamed: C46.2, D41.3 (VCC), R40.2
unnamed: C47.2, D42.3 (VCC), R41.2
unnamed: C48.2, D43.3 (VCC), R42.2
unnamed: D1.1 (K), L1.1, U3.2 (OUT)
unnamed: D2.1 (DOUT), D3.2 (DIN)
unnamed: D3.1 (DOUT), D4.2 (DIN)
unnamed: D4.1 (DOUT), D5.2 (DIN)
unnamed: D5.1 (DOUT), D6.2 (DIN)
unnamed: D6.1 (DOUT), D7.2 (DIN)
unnamed: D7.1 (DOUT), D8.2 (DIN)
unnamed: D8.1 (DOUT), D9.2 (DIN)
unnamed: D10.1 (DOUT), D11.2 (DIN)
unnamed: D9.1 (DOUT), D10.2 (DIN)
unnamed: D11.1 (DOUT), D12.2 (DIN)
unnamed: D12.1 (DOUT), D13.2 (DIN)
unnamed: D13.1 (DOUT), D14.2 (DIN)
unnamed: D14.1 (DOUT), D15.2 (DIN)
unnamed: D15.1 (DOUT), D16.2 (DIN)
unnamed: D16.1 (DOUT), D17.2 (DIN)
unnamed: D17.1 (DOUT), D18.2 (DIN)
unnamed: D18.1 (DOUT), D19.2 (DIN)
unnamed: D19.1 (DOUT), D20.2 (DIN)
unnamed: D20.1 (DOUT), D21.2 (DIN)
unnamed: D21.1 (DOUT), D22.2 (DIN)
unnamed: D22.1 (DOUT), D23.2 (DIN)
unnamed: D23.1 (DOUT), D24.2 (DIN)
unnamed: D24.1 (DOUT), D25.2 (DIN)
unnamed: D25.1 (DOUT), D26.2 (DIN)
unnamed: D26.1 (DOUT), D27.2 (DIN)
unnamed: D27.1 (DOUT), D28.2 (DIN)
unnamed: D28.1 (DOUT), D29.2 (DIN)
unnamed: D29.1 (DOUT), D30.2 (DIN)
unnamed: D30.1 (DOUT), D31.2 (DIN)
unnamed: D31.1 (DOUT), D32.2 (DIN)
unnamed: D32.1 (DOUT), D33.2 (DIN)
unnamed: D33.1 (DOUT), D34.2 (DIN)
unnamed: D34.1 (DOUT), D35.2 (DIN)
unnamed: D35.1 (DOUT), D36.2 (DIN)
unnamed: D36.1 (DOUT), D37.2 (DIN)
unnamed: D37.1 (DOUT), D38.2 (DIN)
unnamed: D38.1 (DOUT), D39.2 (DIN)
unnamed: D39.1 (DOUT), D40.2 (DIN)
unnamed: D40.1 (DOUT), D41.2 (DIN)
unnamed: D41.1 (DOUT), D42.2 (DIN)
unnamed: D42.1 (DOUT), D43.2 (DIN)
unnamed: D45.1 (K), U4.22 (CBUS1)
unnamed: D45.2 (A), R43.2
unnamed: D46.1 (K), U4.23 (CBUS0)
unnamed: D46.2 (A), R44.2
unnamed: D47.1 (K), R49.1
unnamed: J1.3, J2.2
unnamed: J3.2 (D-), U4.16 (USBD-)
unnamed: J3.3 (D+), U4.15 (USBD+)
unnamed: Q1.1 (B), R47.1
unnamed: Q2.1 (B), R48.1
unnamed: Q3.1 (Gate), U5.6
unnamed: R50.2, R51.1, U5.3 (+)
RTS: Q1.3 (E), R48.2, U4.3 (RTS)
RX0: U1.35 (TXD0/IO1), U4.5 (RXD)
TX0: U1.34 (RXD0/IO3), U4.1 (TXD)
VCC: C1.1, C5.1, C6.1, D2.5 (VDD), D3.5 (VDD), D4.5 (VDD), D5.5 (VDD), D6.5 (VDD), D7.5 (VDD), D8.5 (VDD), D9.5 (VDD), D10.5 (VDD), D11.5 (VDD), D12.5 (VDD), D13.5 (VDD), D14.5 (VDD), D15.5 (VDD), D16.5 (VDD), D17.5 (VDD), D18.5 (VDD), D19.5 (VDD), D20.5 (VDD), D21.5 (VDD), D22.5 (VDD), D23.5 (VDD), D24.5 (VDD), D25.5 (VDD), D26.5 (VDD), D27.5 (VDD), D28.5 (VDD), D29.5 (VDD), D30.5 (VDD), D31.5 (VDD), D32.5 (VDD), D33.5 (VDD), D34.5 (VDD), D35.5 (VDD), D36.5 (VDD), D37.5 (VDD), D38.5 (VDD), D39.5 (VDD), D40.5 (VDD), D41.5 (VDD), D42.5 (VDD), D43.5 (VDD), L1.2, Q3.3 (Drain), R1.1, R2.1, R3.1, R4.1, R5.1, R6.1, R7.1, R8.1, R9.1, R10.1, R11.1, R12.1, R13.1, R14.1, R15.1, R16.1, R17.1, R18.1, R19.1, R20.1, R21.1, R22.1, R23.1, R24.1, R25.1, R26.1, R27.1, R28.1, R29.1, R30.1, R31.1, R32.1, R33.1, R34.1, R35.1, R36.1, R37.1, R38.1, R39.1, R40.1, R41.1, R42.1, TP2.1, U2.3 (VIN), U3.3 (FB), U5.7 (V+)
VCCQ: C2.1, D47.2 (A), R45.1, R46.1, R52.1, TP1.1, U1.2 (VDD), U2.2 (VOUT), U5.2 (-)
V_FT232: C49.1, C51.1, SW4.2 (B), TP4.1, U4.20 (VCC)
V_FT_IO: C50.1, R43.1, R44.1, TP5.1, U4.4 (VCCIO), U4.17 (3V3OUT), U4.19 (~RESET~)
V_IN: C3.1, C4.1, D44.1 (K), J1.1, J2.1, R50.1, TP3.1, U3.1 (VIN)
V_USB: J3.1 (VBUS), Q3.2 (Source), SW4.3 (C)

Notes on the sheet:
Regulator 3V3
Regulator 5V
Led Matrix Spielfeld
Reset Logic
USB / UART Wandler
Button Boot
Button Reset
Button Soft Reset
MCU ESP32 WROOM 32D
USB power protection

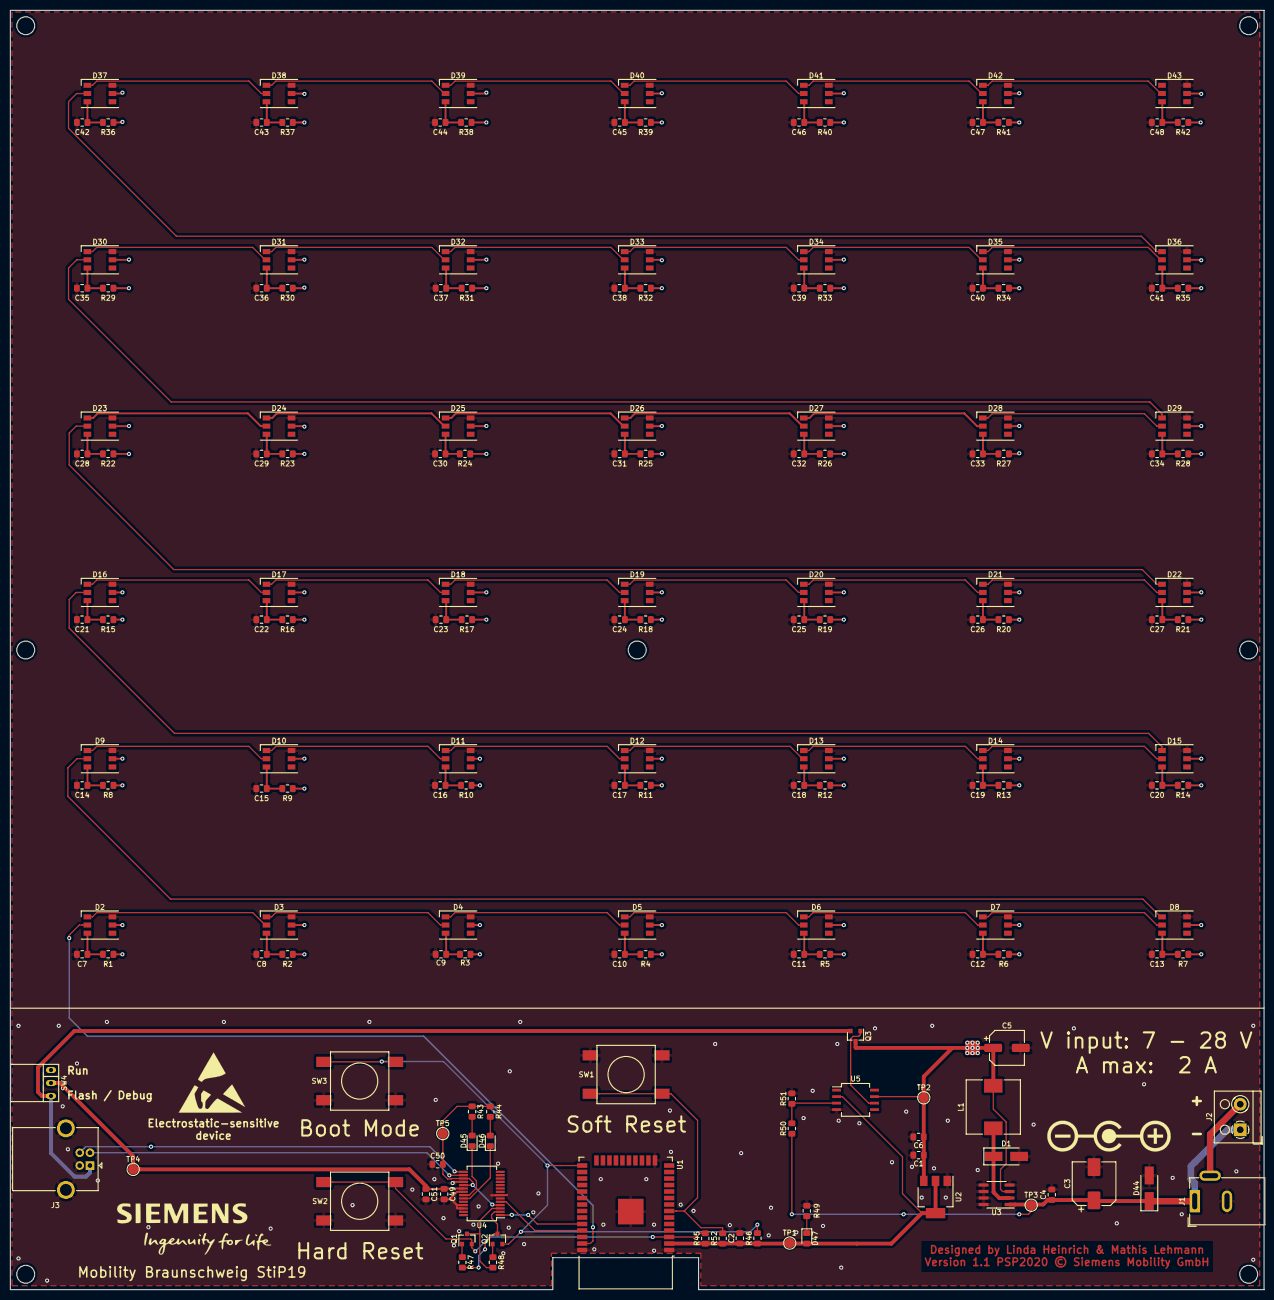
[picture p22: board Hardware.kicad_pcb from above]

Board: 2 copper layers, 245.0 x 250.0 mm, 171 parts (0 on the bottom side), 111 nets.

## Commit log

2020-11-09 Created test project to teach workflow s Please enter the commit message for your changes. Lines starting
    [Testprojekt.kicad_pcb, Testprojekt.sch]
2020-11-09 Testprojekt Platinendesign erstellt
    [Testprojekt.kicad_pcb, Testprojekt.sch]
2020-11-17 Started schematic
    [BOM.xlsx, Hardware.kicad_pcb, Hardware.sch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]
2020-11-17 Spannungsregler hinzugfügt
    [Hardware.sch]
2020-11-17 Elkos ausgewählt
    [Hardware.sch]
2020-11-18 Erweiterung der Bauteilinformationen
    [Hardware.sch]
2020-11-18 Finished LED Matrix Added part datasheets Updated BOM
    [BOM.xlsx, Hardware.sch]
2020-11-18 LED-Matrix Baueilnummerierung hinzugefügt und BOM erweitert
    [BOM.xlsx, Hardware.sch]
2020-11-19 Finished revision V1.0 Updated power supply input
    [BOM.xlsx]
2020-11-30 Added LED matrix spaceing Added Soft-Reset Added Hard-Reset Added USB-Interface Added Programming-Button Added ISP-Programmer Created 3D Frontplate mockup
    [BOM.xlsx, Blendenmatrix.SLDPRT, Hardware.kicad_pcb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]
2020-11-30 Added additional 3D file formats
    [Blendenmatrix.AMF, Blendenmatrix.STL]
2020-11-30 Updated Schematic to be more intuitive to read Updated BOM
    [BOM.xlsx, Hardware.kicad_pcb, Hardware.sch]
2020-12-01 Added Enclosure plan
    [Hardware.kicad_pcb, Hardware.sch]
2020-12-02 Finished PCB Layout V1 Updated Inductor for ripple reduction Rerouted FT232RL traces Added reset logic for ISP programming Added Silkscreen button labels
    [BOM.xlsx, Diffusor.SLDPRT, Hardware.kicad_pcb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]
2020-12-02 Gehäuse Vorderseite erster Entwurf
    [Gehäuse_Vorderseite v0.stl]
2020-12-03 Finished review of Layout Reviewed BOM Added input cutoff form screw terminal when barreljack is used Added branding Added revision Added author Optimised routing Added screw holes for case Updated b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
    [BOM.xlsx, Hardware.kicad_pcb, Hardware.sch]
2020-12-03 Updated documentation Added datasheet for terminal block Updated BOM
    [BOM.xlsx, Hardware.sch]
2020-12-05 Gehäause Vorder- und Rückseite und Taster erstellt
    [Gehäuse_2 v18.f3d]
2020-12-07 Added 3D models for PCB preview rendering Updated Layput with 3D Models
    [Hardware.kicad_pcb, usb_a-usb_b_smt-r.stp]
2020-12-07 Added rendered images to documentation Deleted temporary 3D File
    [Hardware.sch]
2020-12-07 Gehäuse fertig
    [Gehäuse_2 v18.f3d, Gesamtes Gehäuse_v27.f3d]
2020-12-08 .stl Datei des Gehäuses erstellt
    [Gehäuse_Vorderseite v0.stl, Gehäuse_fertiggestellt_v28.f3d, Gehäuse_fertiggestellt_v28.stl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]
2020-12-12 einzelne stl-Dateien erstellt, Höhenunterschied der Taster beseitigt
    [Gehäuse Rückseite.stl, Gehäuse_Vorderseite.stl, Gehäuse_fertiggestellt_v28.f3d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]
2020-12-14 Added urgent features requested by client Added power LED Added option to supply complete PCB via USB port
    [BOM.xlsx, Hardware.kicad_pcb, Hardware.sch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]
2020-12-15 Production readiness Improved reverse USB powerprotection Added part orderlist
    [Hardware.kicad_pcb, Hardware.sch]
2020-12-16 Loch für Schalter und Power-LED zum Gehäuse hinzugefügt
    [Gehäuse_Vorderseite.stl, Gehäuse_v30.f3d, Gehäuse_v31.f3d]
2020-12-16 Finished Layout V1 Created Gerber and Excellion drill files Updated BOM Added order manual Added orderlist Updated Schematic
    [BOM.xlsx, Bestellliste_PSP20_Hardware.xlsx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]
2021-01-28 Verkleinerung der Taster, Schrift auf die Gehäusefront verschoben, kleine Anpassungen
    [Blendenmatrix.STL, Gehäuse Rückseite.stl, GehäuseRückseite.stl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]
2021-02-18 Aussparung der Platine im Gehäuse vergrößert
    [GehäuseVorderseite.stl, Taster_einzelnv1.stl]
2021-02-24 Fixed RX & TX Issue #5 Switched RX & TX of FT232RL and ESP 32.
    [Bestellliste_PSP20_Hardware.xlsx, Hardware.kicad_pcb, Hardware.sch]
2021-02-24 Resolved Issue 6 & Issue 7 Switched Pin 2 & 3 of P-FET (Issue 6) Upgraded P-FET to handle 2A continuous (Issue 7)
    [Hardware.kicad_pcb, Hardware.sch]
2021-02-24 Rerouted feedbackline. close #4 Rerouted to after smoothing coil
    [Hardware.kicad_pcb, Hardware.sch]
2021-02-24 Added Info to silkscreen Polarity info added. close #10, close #3 Added ESD warning Changed revision marker to V1.1 Added switch labeling
    [Hardware.kicad_pcb]
2021-02-24 Added Pullup and conneced floating GND peninsulas Added 10k pullup on Soft Rest button (close #9) Via'd GND peninsulas to GND to prevent oscillation
    [Hardware.kicad_pcb, Hardware.sch]
2021-02-24 Isolated ZLDO tab from GND Isolated ZLDO 1733 tab from GND (close #2)
    [Hardware.kicad_pcb]
2021-02-24 Switched input smoothing cap to 35V rated cap Switched C3 to 35V rated electrolytic capacitor (close #1)
    [Hardware.kicad_pcb, Hardware.sch]
2021-02-24 Updated BOM to match PCB Rev V1.1
    [BOM.xlsx]
2021-03-02 weitere Anpassungen am Gehäuse
    [GehäuseVorderseite.stl, Körper1.stl, Körper2.stl]
2021-03-02 Umbenennen der stl-Datei Taster und Entfernen von veralteten Versionen
    [Körper1.stl, Körper2.stl, Taster.stl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]
2021-04-06 Added Documentation Updated libary references for KiCad

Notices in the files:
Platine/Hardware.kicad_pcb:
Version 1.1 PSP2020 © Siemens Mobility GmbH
